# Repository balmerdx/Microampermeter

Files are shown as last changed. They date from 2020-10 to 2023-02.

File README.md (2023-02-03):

# Микроамперметр

Микроамперметр перфекциониста, с возможностью посмотреть график и гистограмму получаемого тока.
Предназначен для того, что-бы отлаживать низкопотребляющие железки,
которые во сне потребляют микроамперы, а когда проснулись, то могут потреблять десятки миллиампер.

* [Видео с возможностями прибора.](https://www.youtube.com/watch?v=IdX-KkagfNQ)

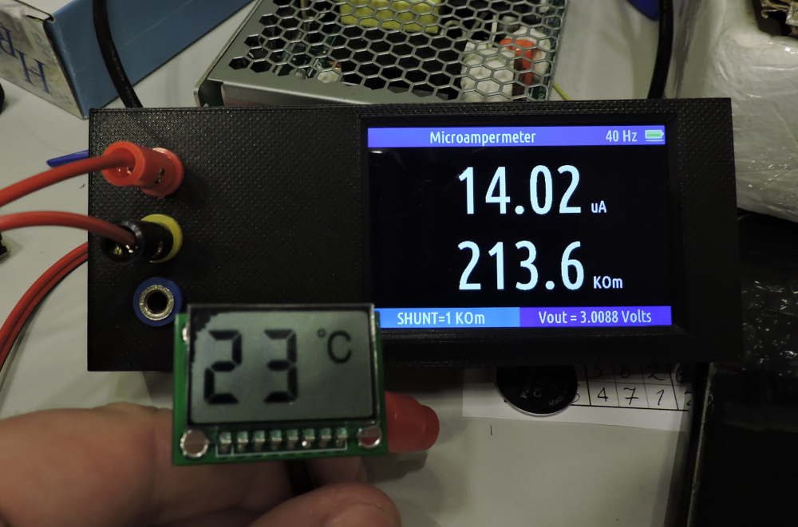
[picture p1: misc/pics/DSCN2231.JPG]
Плата


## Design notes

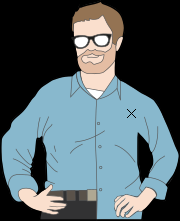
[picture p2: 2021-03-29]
misc/images/balmer.png

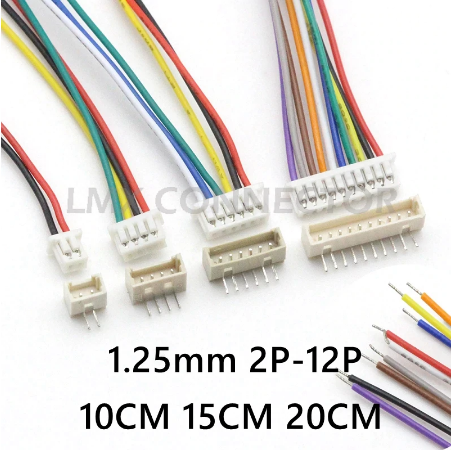
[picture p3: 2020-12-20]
kicad/stm32h7_digital/pinheader.png

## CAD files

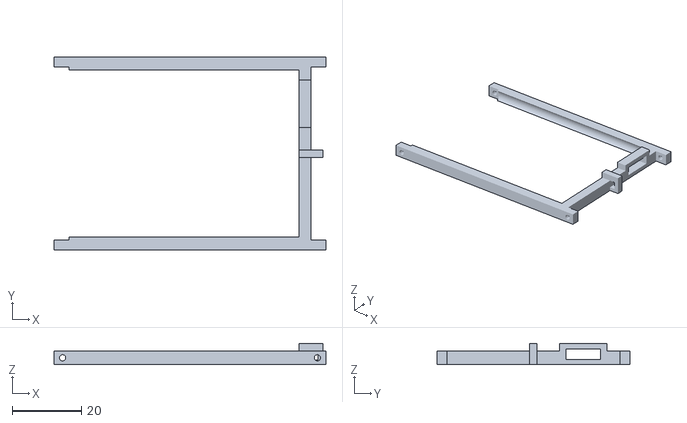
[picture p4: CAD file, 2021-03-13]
misc/3d/battery_holder.stl
78.7 x 55.8 x 6.20

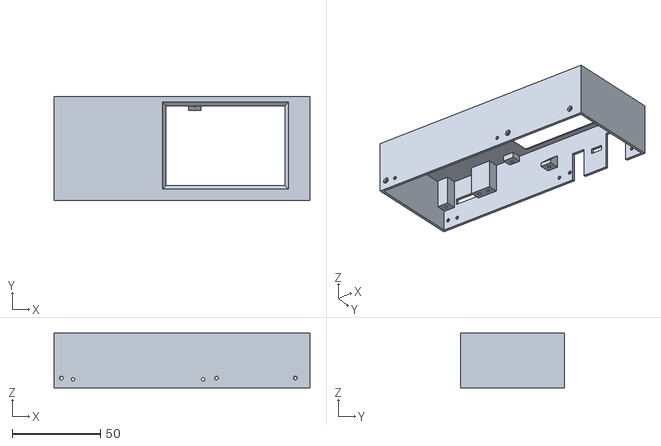
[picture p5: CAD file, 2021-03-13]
misc/3d/microampermeter_top.stl
145.0 x 58.8 x 31.0

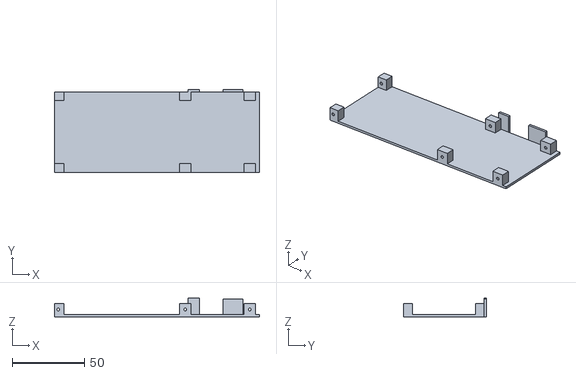
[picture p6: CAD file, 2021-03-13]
misc/3d/microampermeter_bottom.stl
141.8 x 57.2 x 12.9

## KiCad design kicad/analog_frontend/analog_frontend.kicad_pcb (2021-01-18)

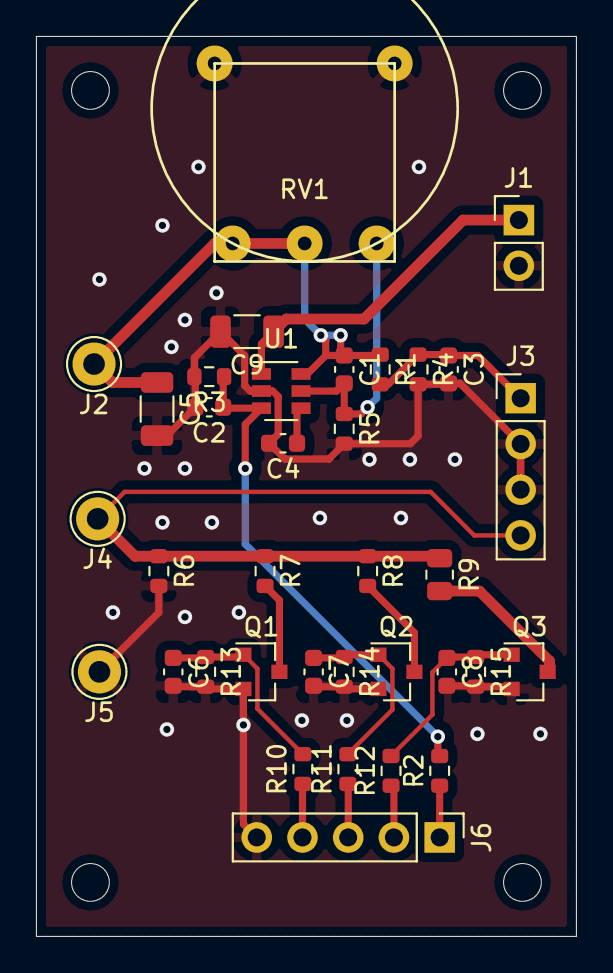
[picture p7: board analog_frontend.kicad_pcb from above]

Board: 2 copper layers, 30.0 x 50.0 mm, 35 parts (0 on the bottom side), 18 nets.

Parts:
C1: 22; C_0603_1608Metric
C2, C6, C7, C8: 22n; C_0603_1608Metric
C3: 1n; C_0603_1608Metric
C4: 10n; C_0603_1608Metric
C5: 25u; C_1206_3216Metric
C9: 10u; C_1206_3216Metric
J1: Power; PinHeader_1x02_P2.54mm_Vertical
J2: Vout; Pin_D1.0mm_L10.0mm_LooseFit
J3: ADC; PinHeader_1x04_P2.54mm_Vertical
J4: Isense; Pin_D1.0mm_L10.0mm_LooseFit
J5: GND; Pin_D1.0mm_L10.0mm_LooseFit
J6: Digital; PinHeader_1x05_P2.54mm_Vertical
Q1, Q2: SI2302; SOT-23
Q3: IRLML2502; SOT-23
R1, R4: 2k; R_0603_1608Metric
R2, R5: 10k; R_0603_1608Metric
R3: 330k; R_0603_1608Metric
R6: 1k; R_0603_1608Metric
R7: 100; R_0603_1608Metric
R8: 10; R_0603_1608Metric
R9: 1; R_0805_2012Metric
R10, R11, R12: 4.7k; R_0603_1608Metric
R13, R14, R15: 68k; R_0603_1608Metric
RV1: 20k; Potentiometer_10mm
U1: TPS79301-EP; SOT-23-6

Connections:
+BATT: C9.1, J1.1, U1.1
/Vout: C1.1, C5.1, J2.1, R1.1, RV1.1, RV1.2, U1.6
EN_V: J6.1, R2.1
GND: C2.2, C3.2, C4.2, C5.2, C6.2, C7.2, C8.2, C9.2, J1.2, J3.2, J3.3, J5.1, J6.5, Q1.2, Q2.2, Q3.2, R3.2, R4.2, R5.2, R6.2, R13.2, R14.2, R15.2, RV1.4, RV1.5, U1.2
I_ADC: J3.4, J4.1, R6.1, R7.1, R8.1, R9.1
unnamed: C1.2, R5.1, RV1.3, U1.5
unnamed: C2.1, R2.2, R3.1, U1.3
unnamed: C4.1, U1.4
unnamed: C6.1, Q1.1, R10.2, R13.1
unnamed: C7.1, Q2.1, R11.2, R14.1
unnamed: C8.1, Q3.1, R12.2, R15.1
unnamed: Q1.3, R7.2
unnamed: Q2.3, R8.2
unnamed: Q3.3, R9.2
ON_1: J6.2, R12.1
ON_10: J6.3, R11.1
ON_100: J6.4, R10.1
V_ADC: C3.1, J3.1, R1.2, R4.1

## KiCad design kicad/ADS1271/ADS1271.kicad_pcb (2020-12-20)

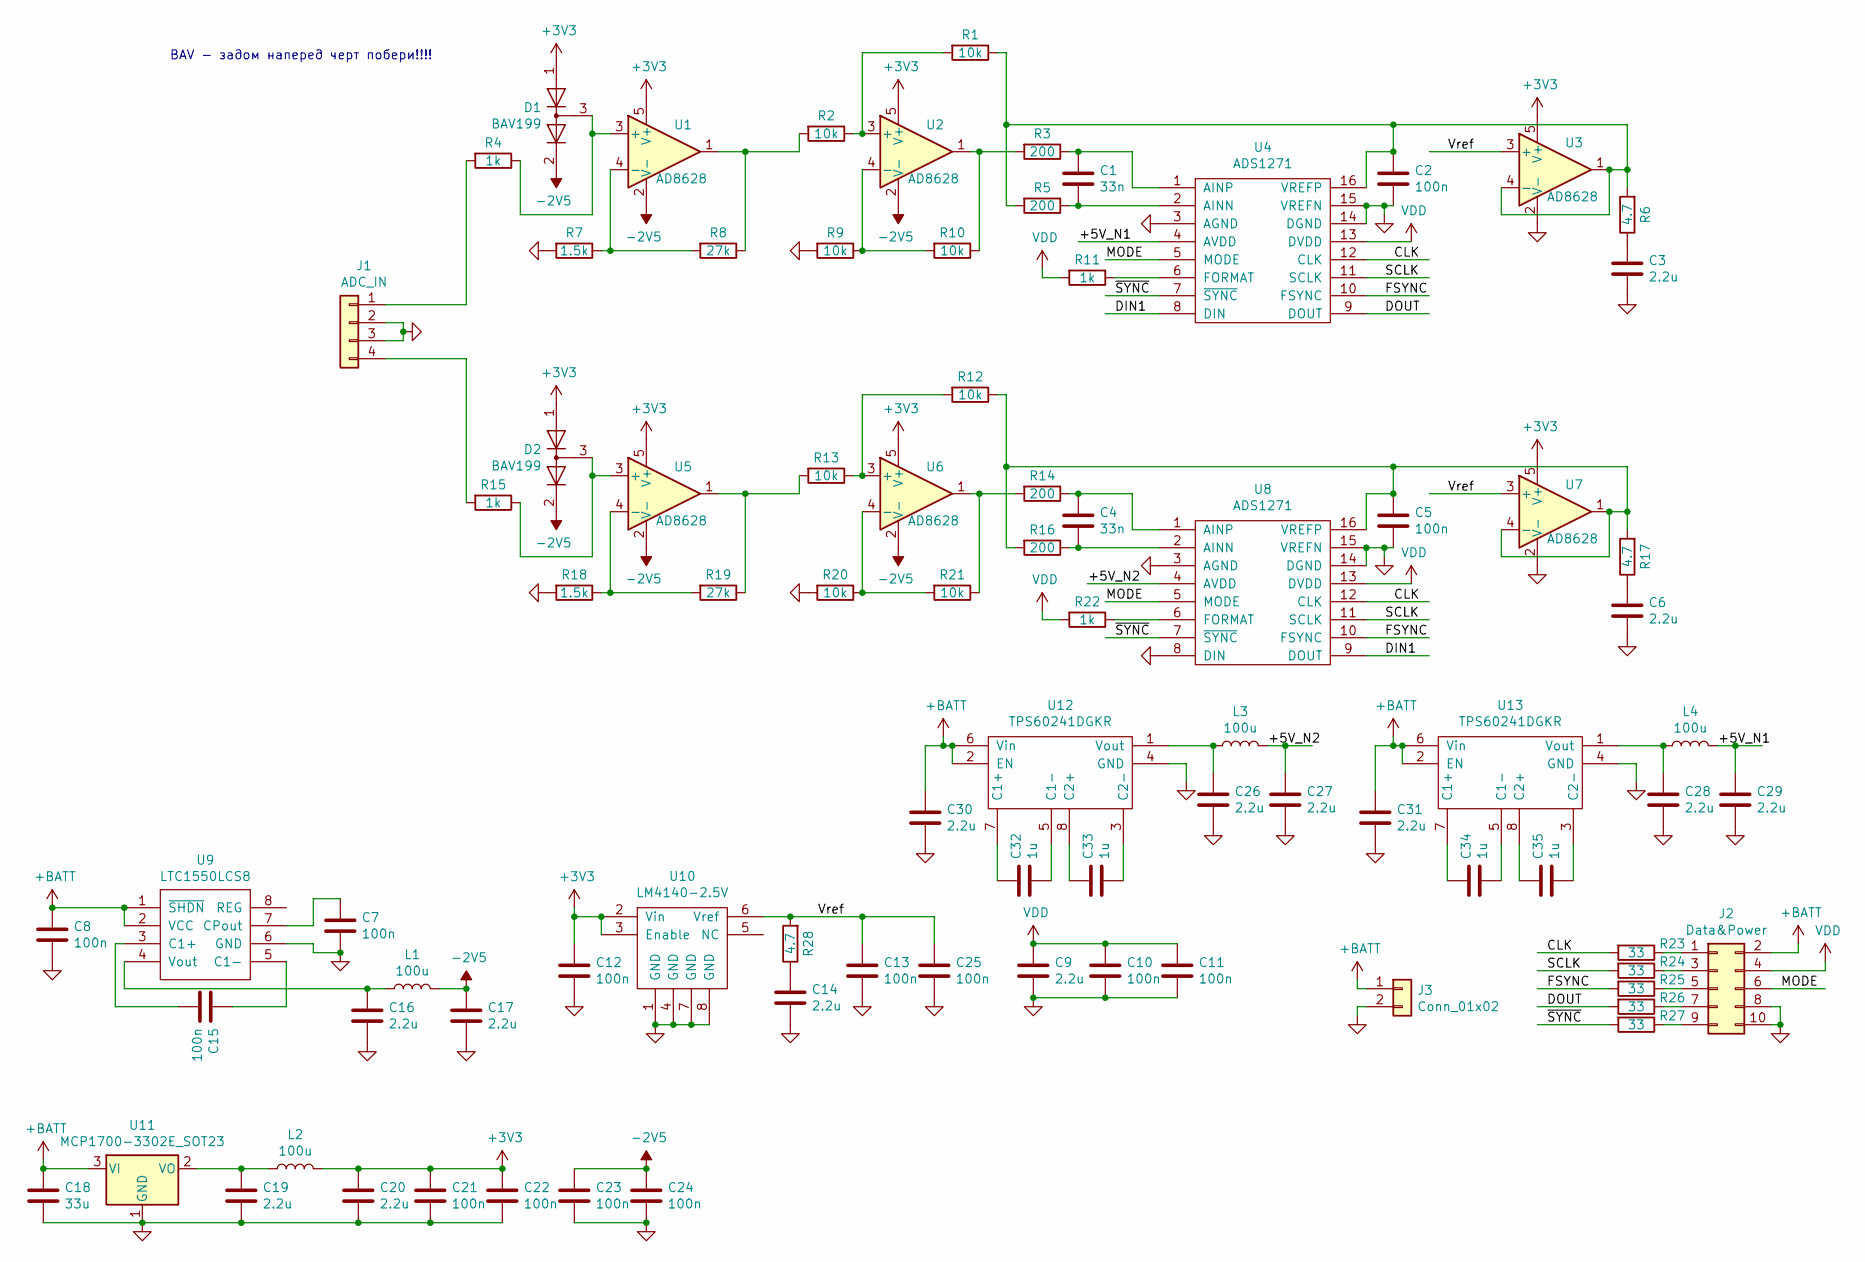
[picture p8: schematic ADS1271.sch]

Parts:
C1, C4: 33n; C_Disc_D7.5mm_W2.5mm_P5.00mm
C2, C5, C7, C8, C10, C11, C12, C13, C15, C21, C22, C23, C24, C25: 100n; C_0603_1608Metric
C3, C6, C9, C14, C16, C17, C19, C20, C26, C27, C28, C29, C30, C31: 2.2u; C_0805_2012Metric
C18: 33u; C_1206_3216Metric
C32, C33, C34, C35: 1u; C_0603_1608Metric
D1, D2: BAV199; SOT-23
J1: ADC_IN; PinHeader_1x04_P2.54mm_Vertical
J2: Data&Power; PinHeader_2x05_P2.54mm_Horizontal
J3: Conn_01x02; PinHeader_1x02_P2.54mm_Vertical
L1, L2, L3, L4: 100u; L_Axial_L9.5mm_D4.0mm_P12.70mm_Horizontal_Fastron_SMCC
R1, R2, R9, R10, R12, R13, R20, R21: 10k; R_0603_1608Metric
R3, R5, R14, R16: 200; R_0603_1608Metric
R4, R11, R15, R22: 1k; R_0603_1608Metric
R6, R17, R28: 4.7; R_0603_1608Metric
R7, R18: 1.5k; R_0603_1608Metric
R8, R19: 27k; R_0603_1608Metric
R23, R24, R25, R26, R27: 33; R_0603_1608Metric
U1, U2, U3, U5, U6, U7: AD8628; SOT-23-5
U4, U8: ADS1271; TSSOP-16_4.4x5mm_P0.65mm
U9: LTC1550LCS8; TSSOP-8_3x3mm_P0.65mm
U10: LM4140-2.5V; SO-8_3.9x4.9mm_P1.27mm
U11: MCP1700-3302E_SOT23; SOT-23
U12, U13: TPS60241DGKR; TSSOP-8_3x3mm_P0.65mm

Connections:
+3V3: C12.1, C20.1, C21.1, C22.1, D1.1 (K), D2.1 (K), L2.2, U1.5 (V+), U2.5 (V+), U3.5 (V+), U5.5 (V+), U6.5 (V+), U7.5 (V+), U10.2 (Vin), U10.3 (Enable)
+BATT: C8.1, C18.1, C30.1, C31.1, J2.2, J3.1, U9.1 (~SHDN), U9.2 (VCC), U11.3 (VI), U12.2 (EN), U12.6 (Vin), U13.2 (EN), U13.6 (Vin)
-2V5: C17.1, C23.1, C24.1, D1.2 (A), D2.2 (A), L1.2, U1.2 (V-), U2.2 (V-), U5.2 (V-), U6.2 (V-)
/+5V_N1: C29.1, L4.2, U4.4 (AVDD)
/+5V_N2: C27.1, L3.2, U8.4 (AVDD)
/CLK: R23.2, U4.12 (CLK), U8.12 (CLK)
/DIN1: U4.8 (DIN), U8.9 (DOUT)
/DOUT: R26.2, U4.9 (DOUT)
/FSYNC: R25.2, U4.10 (FSYNC), U8.10 (FSYNC)
/MODE: J2.6, U4.5 (MODE), U8.5 (MODE)
/SCLK: R24.2, U4.11 (SCLK), U8.11 (SCLK)
/Vref: C13.1, C25.1, R28.2, U3.3 (+), U7.3 (+), U10.6 (Vref)
/~SYNC: R27.2, U4.7 (~SYNC), U8.7 (~SYNC)
GND: C2.2, C3.2, C5.2, C6.2, C7.2, C8.2, C9.2, C10.2, C11.2, C12.2, C13.2, C14.2, C16.2, C17.2, C18.2, C19.2, C20.2, C21.2, C22.2, C23.2, C24.2, C25.2, C26.2, C27.2, C28.2, C29.2, C30.2, C31.2, J1.2, J1.3, J2.8, J2.10, J3.2, R7.2, R9.2, R18.2, R20.2, U3.2 (V-), U4.3 (AGND), U4.14 (DGND), U4.15 (VREFN), U7.2 (V-), U8.3 (AGND), U8.8 (DIN), U8.14 (DGND), U8.15 (VREFN), U9.6 (GND), U10.1 (GND), U10.4 (GND), U10.7 (GND), U10.8 (GND), U11.1 (GND), U12.4 (GND), U13.4 (GND)
unnamed: C1.1, R3.1, U4.1 (AINP)
unnamed: C1.2, R5.1, U4.2 (AINN)
unnamed: C2.1, R1.1, R5.2, R6.2, U3.1, U3.4 (-), U4.16 (VREFP)
unnamed: C3.1, R6.1
unnamed: C4.1, R14.1, U8.1 (AINP)
unnamed: C4.2, R16.1, U8.2 (AINN)
unnamed: C5.1, R12.1, R16.2, R17.2, U7.1, U7.4 (-), U8.16 (VREFP)
unnamed: C6.1, R17.1
unnamed: C7.1, U9.7 (CPout)
unnamed: C14.1, R28.1
unnamed: C15.1, U9.5 (C1-)
unnamed: C15.2, U9.3 (C1+)
unnamed: C16.1, L1.1, U9.4 (Vout)
unnamed: C19.1, L2.1, U11.2 (VO)
unnamed: C26.1, L3.1, U12.1 (Vout)
unnamed: C28.1, L4.1, U13.1 (Vout)
unnamed: C32.1, U12.7 (C1+)
unnamed: C32.2, U12.5 (C1-)
unnamed: C33.1, U12.8 (C2+)
unnamed: C33.2, U12.3 (C2-)
unnamed: C34.1, U13.7 (C1+)
unnamed: C34.2, U13.5 (C1-)
unnamed: C35.1, U13.8 (C2+)
unnamed: C35.2, U13.3 (C2-)
unnamed: D1.3 (K), R4.1, U1.3 (+)
unnamed: D2.3 (K), R15.1, U5.3 (+)
unnamed: J1.1, R4.2
unnamed: J1.4, R15.2
unnamed: J2.1, R23.1
unnamed: J2.3, R24.1
unnamed: J2.5, R25.1
unnamed: J2.7, R26.1
unnamed: J2.9, R27.1
unnamed: R1.2, R2.1, U2.3 (+)
unnamed: R2.2, R8.1, U1.1
unnamed: R7.1, R8.2, U1.4 (-)
unnamed: R3.2, R10.1, U2.1
unnamed: R9.1, R10.2, U2.4 (-)
unnamed: R11.1, U4.6 (FORMAT)
unnamed: R12.2, R13.1, U6.3 (+)
unnamed: R13.2, R19.1, U5.1
unnamed: R14.2, R21.1, U6.1
unnamed: R18.1, R19.2, U5.4 (-)
unnamed: R20.1, R21.2, U6.4 (-)
unnamed: R22.1, U8.6 (FORMAT)
VDD: C9.1, C10.1, C11.1, J2.4, R11.2, R22.2, U4.13 (DVDD), U8.13 (DVDD)

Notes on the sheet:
BAV - задом наперед черт побери!!!!

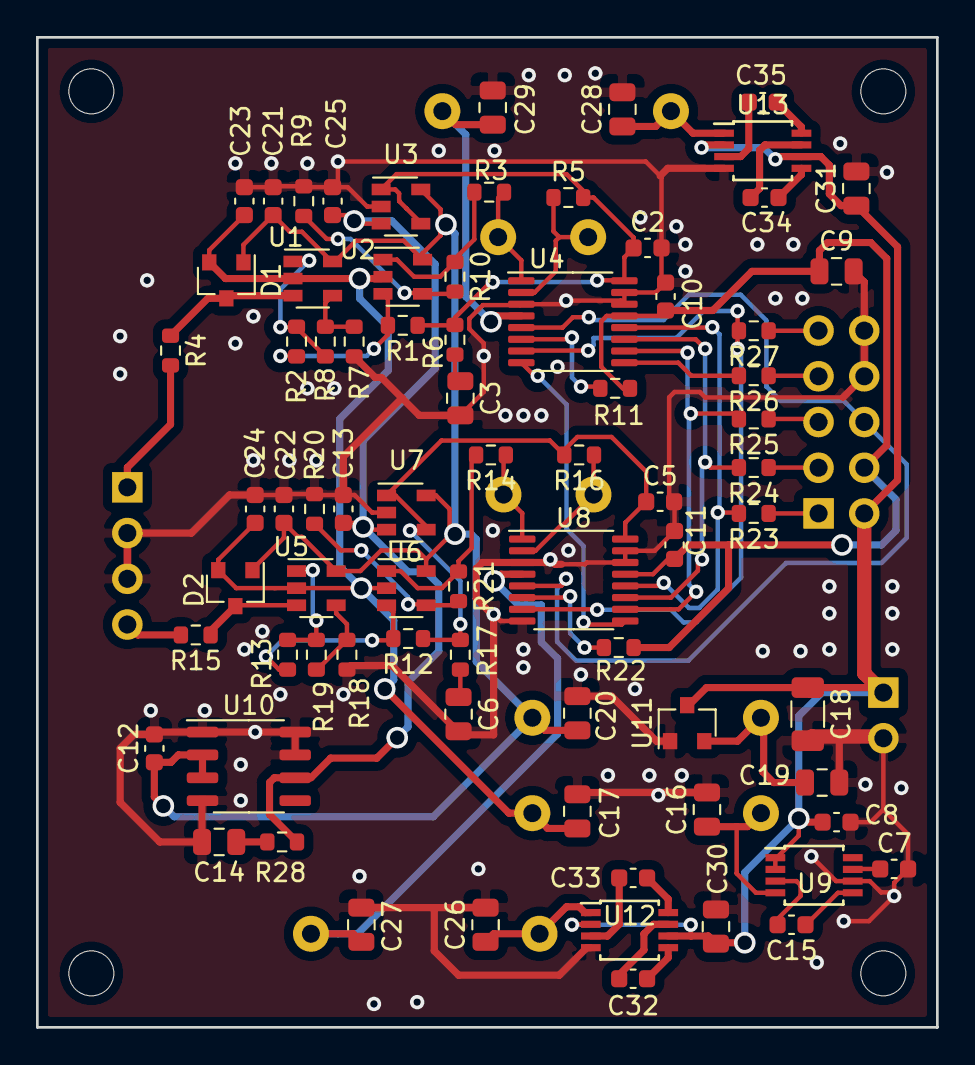
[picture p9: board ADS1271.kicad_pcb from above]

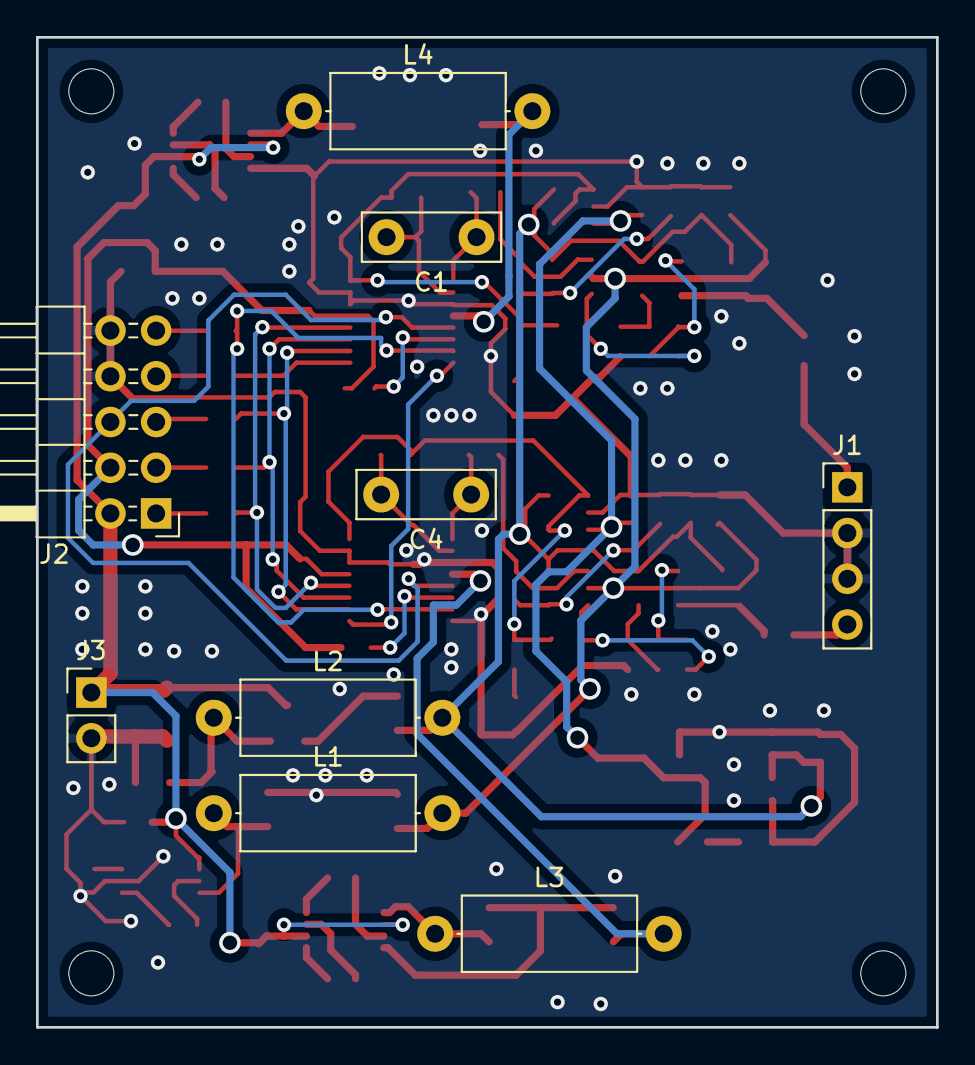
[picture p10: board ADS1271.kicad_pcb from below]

Board: 2 copper layers, 50.0 x 55.0 mm, 85 parts (9 on the bottom side), 60 nets.

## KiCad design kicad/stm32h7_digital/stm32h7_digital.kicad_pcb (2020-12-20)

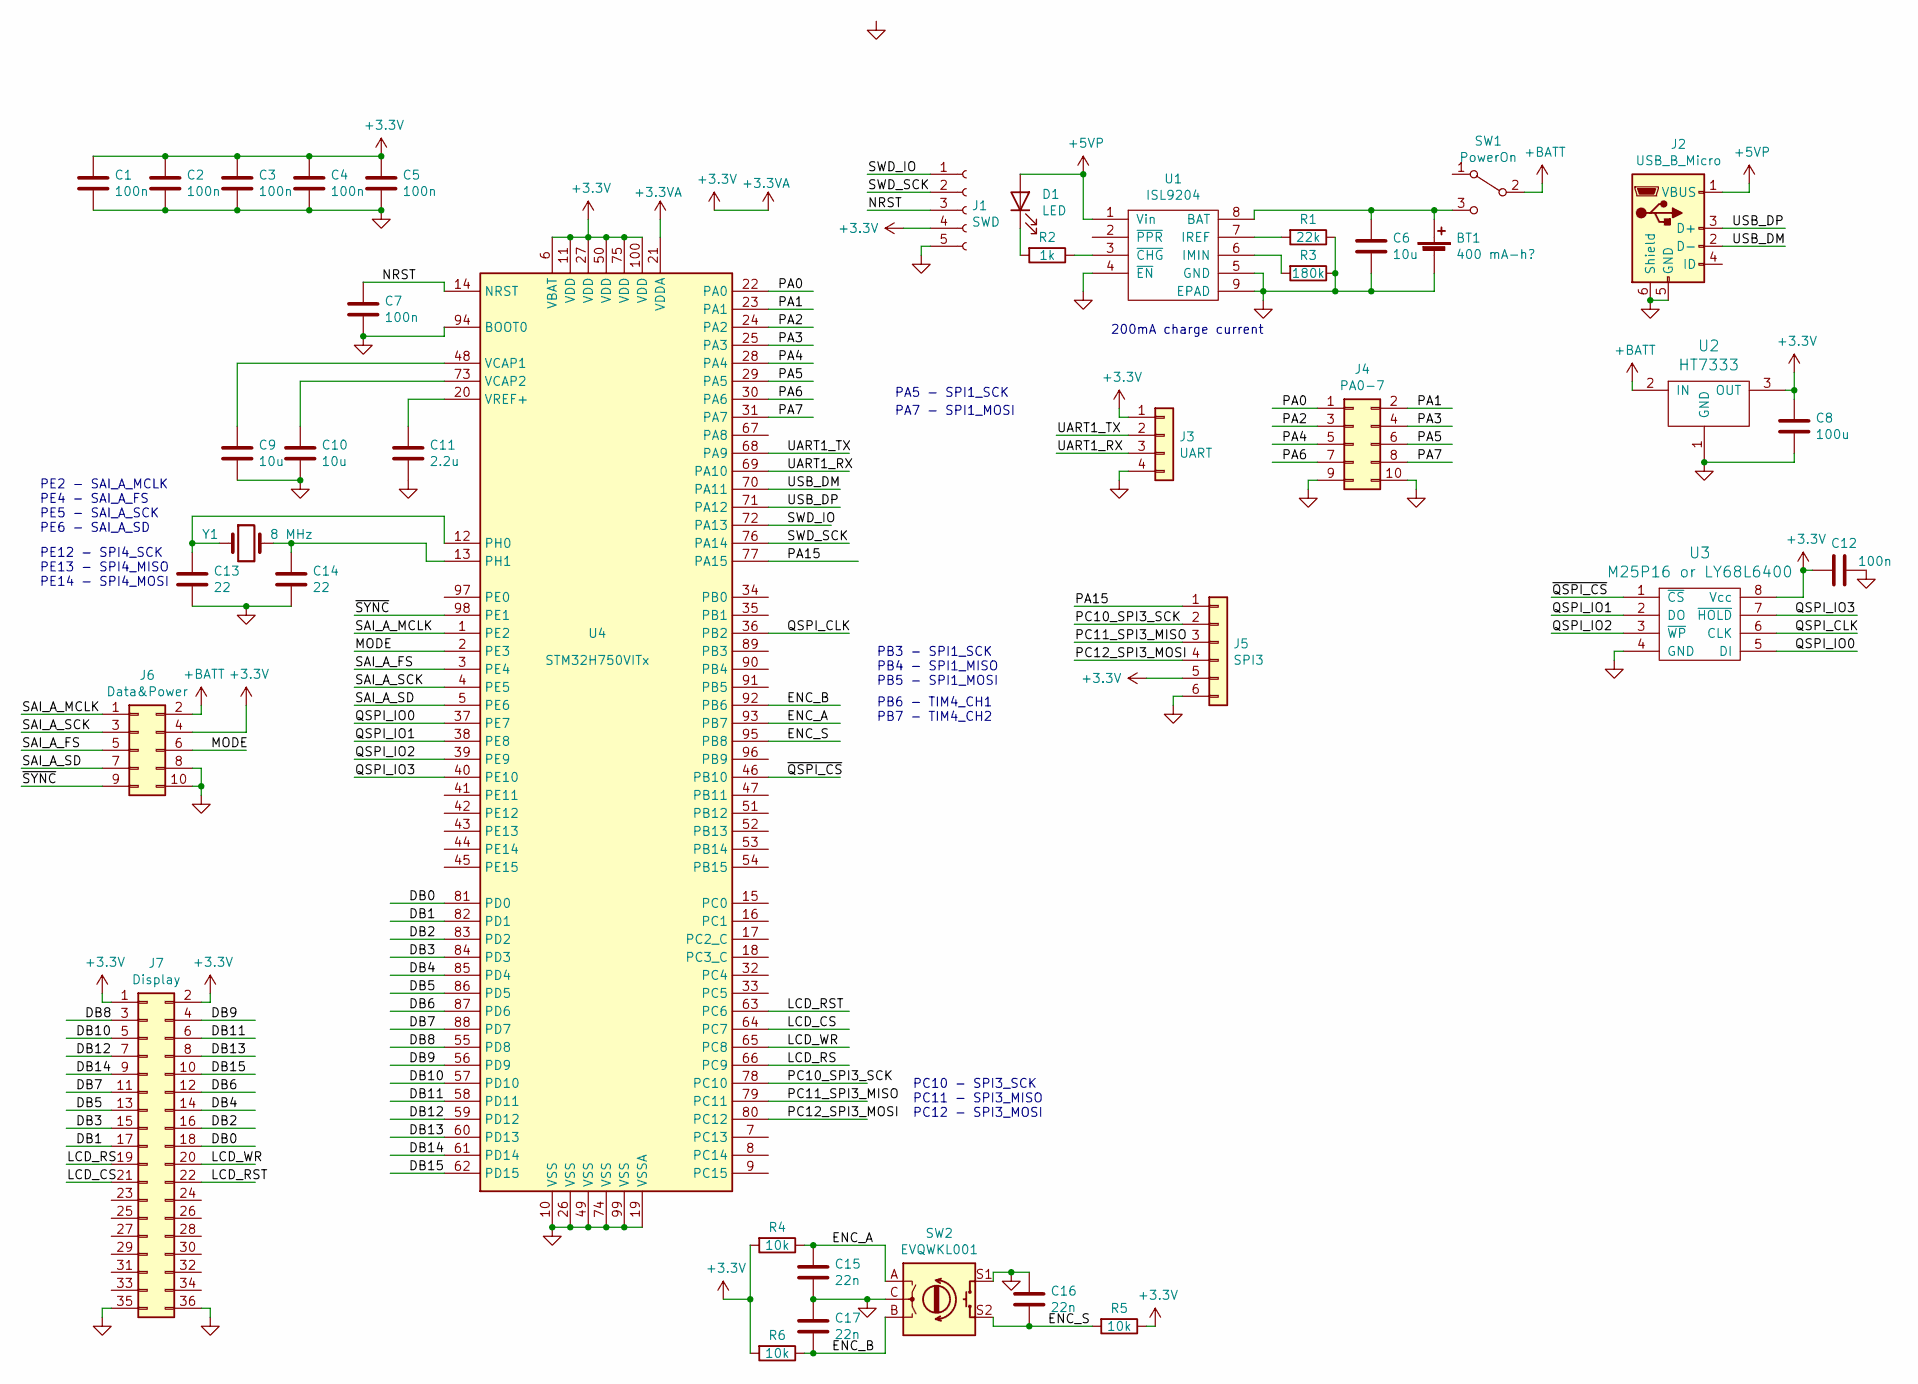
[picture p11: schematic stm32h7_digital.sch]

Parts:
BT1: 400 mA-h?; PinSocket_1x02_P2.54mm_Vertical
C1, C2, C3, C4, C5, C7, C12: 100n; C_0603_1608Metric
C6, C9, C10: 10u; C_1206_3216Metric
C8: 100u; C_1206_3216Metric
C11: 2.2u; C_0805_2012Metric
C13, C14: 22; C_0603_1608Metric
C15, C16, C17: 22n; C_0603_1608Metric
D1: LED; LED_0805_2012Metric_Pad1.15x1.40mm_HandSolder
J1: SWD; PinSocket_1x05_P1.27mm_Vertical
J2: USB_B_Micro; USB_Micro-B_Molex-105017-0001
J3: UART; PinHeader_1x04_P2.54mm_Horizontal
J4: PA0-7; PinSocket_2x05_P2.54mm_Horizontal
J5: SPI3; PinSocket_1x06_P1.27mm_Vertical
J6: Data&Power; PinSocket_2x05_P2.54mm_Horizontal
J7: Display; PinHeader_2x18_P2.54mm_Vertical
R1: 22k; R_0603_1608Metric
R2: 1k; R_0603_1608Metric
R3: 180k; R_0603_1608Metric
R4, R5, R6: 10k; R_0603_1608Metric
SW1: PowerOn; SW_Angled_with_GND
SW2: EVQWKL001; Encoder_EVQWK4
U1: ISL9204; DFN-8-1EP_3x2mm_P0.5mm_EP1.75x1.65mm
U2: HT7333; SOT-89-3
U3: M25P16 or LY68L6400; SOIC-8_3.9x4.9mm_P1.27mm
U4: STM32H750VITx; LQFP-100_14x14mm_P0.5mm
Y1: 8 MHz; Crystal_SMD_5032-2Pin_5.0x3.2mm

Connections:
+3.3VA: C1.1, C2.1, C3.1, C4.1, C5.1, C8.1, C12.2, J1.4, J3.1, J5.5, J6.4, J7.1, J7.2, R4.2, R5.1, R6.2, U2.3 (OUT), U3.8 (Vcc), U4.6 (VBAT), U4.11 (VDD), U4.21 (VDDA), U4.27 (VDD), U4.50 (VDD), U4.75 (VDD), U4.100 (VDD)
+5VP: D1.2 (A), J2.1 (VBUS), U1.1 (Vin)
+BATT: J6.2, SW1.2 (B), U2.2 (IN)
/DB0: J7.18, U4.81 (PD0)
/DB1: J7.17, U4.82 (PD1)
/DB2: J7.16, U4.83 (PD2)
/DB3: J7.15, U4.84 (PD3)
/DB4: J7.14, U4.85 (PD4)
/DB5: J7.13, U4.86 (PD5)
/DB6: J7.12, U4.87 (PD6)
/DB7: J7.11, U4.88 (PD7)
/DB8: J7.3, U4.55 (PD8)
/DB9: J7.4, U4.56 (PD9)
/DB10: J7.5, U4.57 (PD10)
/DB11: J7.6, U4.58 (PD11)
/DB12: J7.7, U4.59 (PD12)
/DB13: J7.8, U4.60 (PD13)
/DB14: J7.9, U4.61 (PD14)
/DB15: J7.10, U4.62 (PD15)
/ENC_A: C15.1, R4.1, SW2.A, U4.93 (PB7)
/ENC_B: C17.2, R6.1, SW2.B, U4.92 (PB6)
/ENC_S: C16.2, R5.2, SW2.S2, U4.95 (PB8)
/LCD_CS: J7.21, U4.64 (PC7)
/LCD_RS: J7.19, U4.66 (PC9)
/LCD_RST: J7.22, U4.63 (PC6)
/LCD_WR: J7.20, U4.65 (PC8)
/MODE: J6.6, U4.2 (PE3)
/NRST: C7.1, J1.3, U4.14 (NRST)
/PA0: J4.1, U4.22 (PA0)
/PA1: J4.2, U4.23 (PA1)
/PA2: J4.3, U4.24 (PA2)
/PA3: J4.4, U4.25 (PA3)
/PA4: J4.5, U4.28 (PA4)
/PA5: J4.6, U4.29 (PA5)
/PA6: J4.7, U4.30 (PA6)
/PA7: J4.8, U4.31 (PA7)
/PA15: J5.1, U4.77 (PA15)
/PC10_SPI3_SCK: J5.2, U4.78 (PC10)
/PC11_SPI3_MISO: J5.3, U4.79 (PC11)
/PC12_SPI3_MOSI: J5.4, U4.80 (PC12)
/QSPI_CLK: U3.6 (CLK), U4.36 (PB2)
/QSPI_IO0: U3.5 (DI), U4.37 (PE7)
/QSPI_IO1: U3.2 (DO), U4.38 (PE8)
/QSPI_IO2: U3.3 (~WP), U4.39 (PE9)
/QSPI_IO3: U3.7 (~HOLD), U4.40 (PE10)
/SAI_A_FS: J6.5, U4.3 (PE4)
/SAI_A_MCLK: J6.1, U4.1 (PE2)
/SAI_A_SCK: J6.3, U4.4 (PE5)
/SAI_A_SD: J6.7, U4.5 (PE6)
/SWD_IO: J1.1, U4.72 (PA13)
/SWD_SCK: J1.2, U4.76 (PA14)
/UART1_RX: J3.3, U4.69 (PA10)
/UART1_TX: J3.2, U4.68 (PA9)
/USB_DM: J2.2 (D-), U4.70 (PA11)
/USB_DP: J2.3 (D+), U4.71 (PA12)
/~QSPI_CS: U3.1 (~CS), U4.46 (PB10)
/~SYNC: J6.9, U4.98 (PE1)
GND: BT1.2 (-), C1.2, C2.2, C3.2, C4.2, C5.2, C6.2, C7.2, C8.2, C9.2, C10.2, C11.2, C12.1, C13.2, C14.2, C15.2, C16.1, C17.1, J1.5, J2.5 (GND), J2.6 (Shield), J3.4, J4.9, J4.10, J5.6, J6.8, J6.10, J7.35, J7.36, R1.1, R3.1, SW2.C, SW2.GND, SW2.PAD, SW2.S1, U1.4 (~EN), U1.5 (GND), U1.9 (EPAD), U2.1 (GND), U3.4 (GND), U4.10 (VSS), U4.19 (VSSA), U4.26 (VSS), U4.49 (VSS), U4.74 (VSS), U4.94 (BOOT0), U4.99 (VSS)
unnamed: BT1.1 (+), C6.1, SW1.3 (C), U1.8 (BAT)
unnamed: C9.1, U4.48 (VCAP1)
unnamed: C10.1, U4.73 (VCAP2)
unnamed: C11.1, U4.20 (VREF+)
unnamed: C13.1, U4.12 (PH0), Y1.1
unnamed: C14.1, U4.13 (PH1), Y1.2
unnamed: D1.1 (K), R2.2
unnamed: R1.2, U1.7 (IREF)
unnamed: R2.1, U1.3 (~CHG)
unnamed: R3.2, U1.6 (IMIN)

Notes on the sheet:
200mA charge current
PB3 - SPI1_SCK PB4 - SPI1_MISO PB5 - SPI1_MOSI
PC10 - SPI3_SCK PC11 - SPI3_MISO PC12 - SPI3_MOSI
PB6 - TIM4_CH1 PB7 - TIM4_CH2
PA5 - SPI1_SCK
PA7 - SPI1_MOSI
PE12 - SPI4_SCK PE13 - SPI4_MISO PE14 - SPI4_MOSI
PE2 - SAI_A_MCLK PE4 - SAI_A_FS PE5 - SAI_A_SCK PE6 - SAI_A_SD

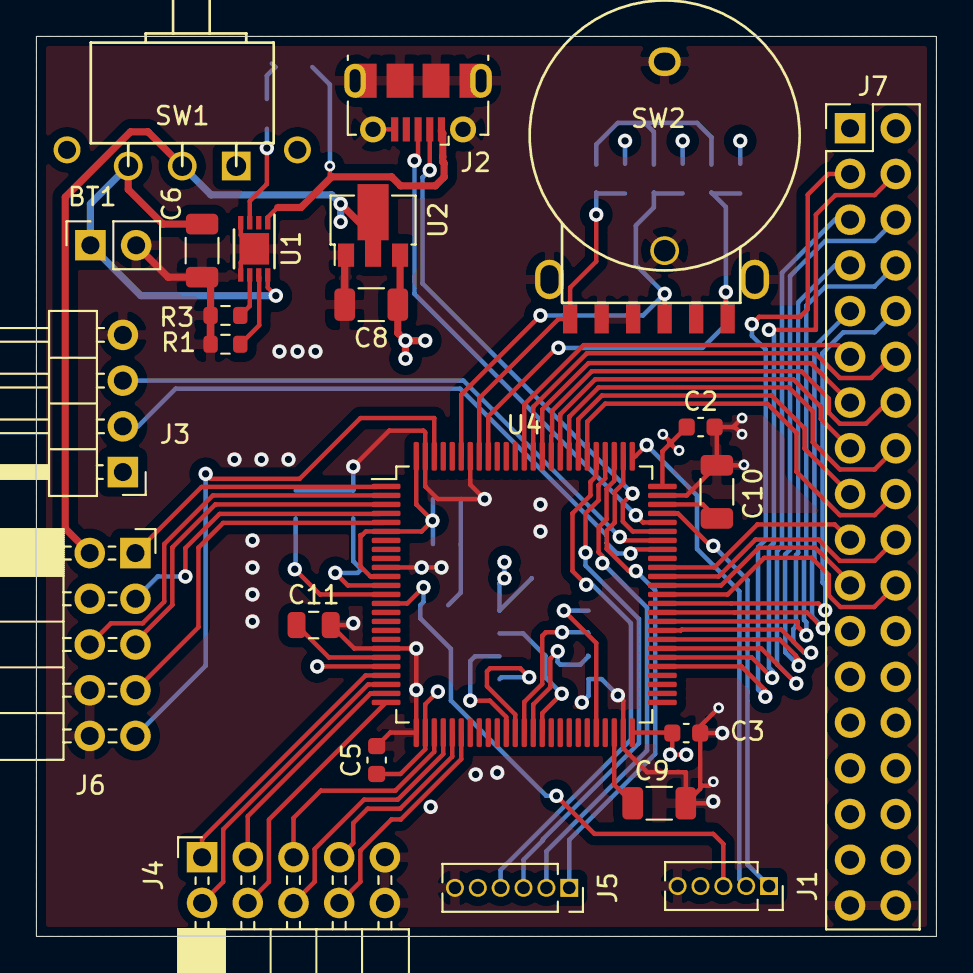
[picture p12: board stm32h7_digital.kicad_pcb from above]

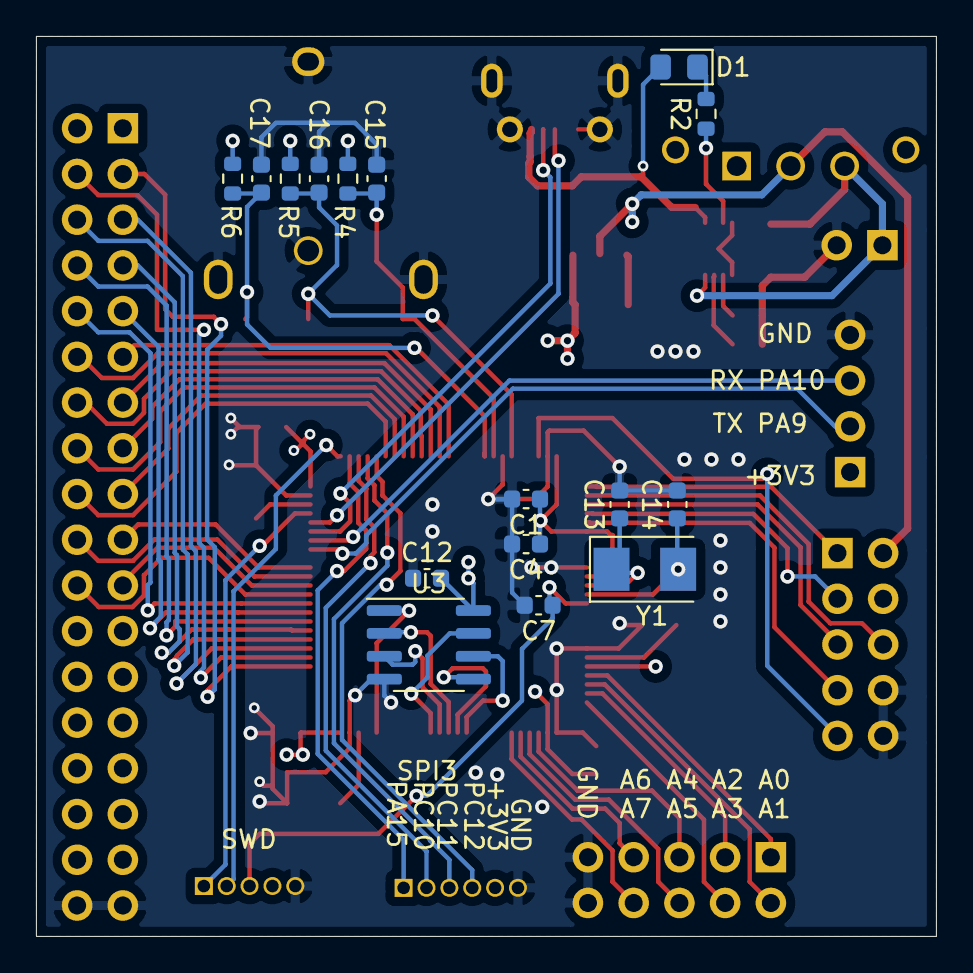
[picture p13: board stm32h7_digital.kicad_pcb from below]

Board: 4 copper layers, 50.0 x 50.0 mm, 39 parts (16 on the bottom side), 68 nets.

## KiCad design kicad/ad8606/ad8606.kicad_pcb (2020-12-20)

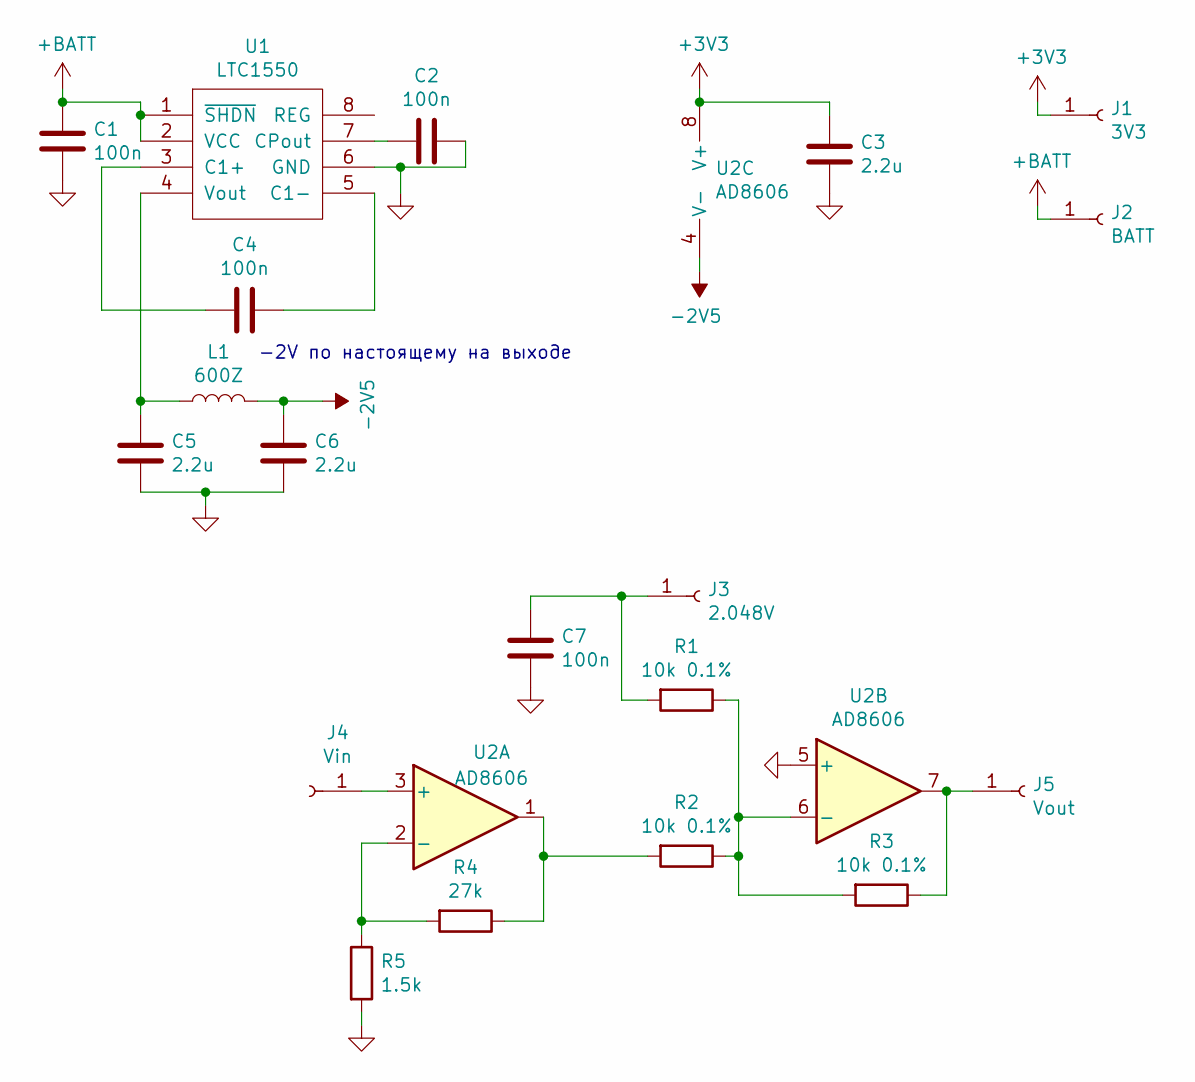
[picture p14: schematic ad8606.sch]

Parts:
C1, C2, C4, C7: 100n; C_0603_1608Metric
C3, C5, C6: 2.2u; C_0805_2012Metric
J1: 3V3; TestPoint_Pad_1.5x1.5mm
J2: BATT; TestPoint_Pad_1.5x1.5mm
J3: 2.048V; TestPoint_Pad_1.5x1.5mm
J4: Vin; TestPoint_Pad_1.5x1.5mm
J5: Vout; TestPoint_Pad_1.5x1.5mm
L1: 600Z; L_1206_3216Metric
R1, R2, R3: 10k 0.1%; R_0603_1608Metric
R4: 27k; R_0603_1608Metric
R5: 1.5k; R_0603_1608Metric
U1: LTC1550; TSSOP-8_3x3mm_P0.65mm
U2: AD8606; TSSOP-8_3x3mm_P0.65mm

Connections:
+3V3: C3.1, J1.1, U2.8 (V+)
+BATT: C1.2, J2.1, U1.1 (~SHDN), U1.2 (VCC)
-2V5: C6.1, L1.2, U2.4 (V-)
GND: C1.1, C2.1, C3.2, C5.2, C6.2, C7.1, R5.2, U1.6 (GND), U2.5 (+)
unnamed: C2.2, U1.7 (CPout)
unnamed: C4.1, U1.5 (C1-)
unnamed: C4.2, U1.3 (C1+)
unnamed: C5.1, L1.1, U1.4 (Vout)
unnamed: C7.2, J3.1, R1.2
unnamed: J4.1, U2.3 (+)
unnamed: J5.1, R3.1, U2.7
unnamed: R1.1, R2.1, R3.2, U2.6 (-)
unnamed: R2.2, R4.1, U2.1
unnamed: R4.2, R5.1, U2.2 (-)

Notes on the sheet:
-2V по настоящему на выходе

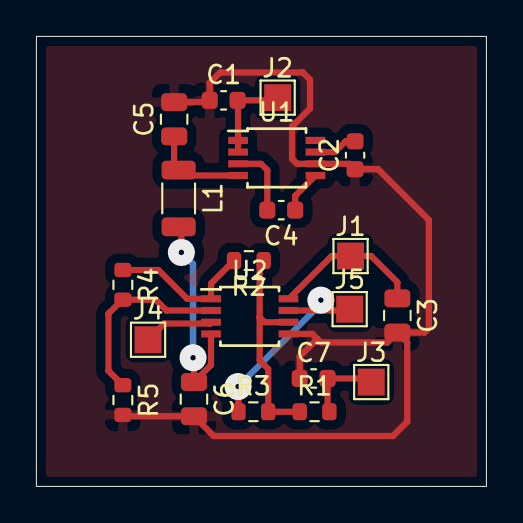
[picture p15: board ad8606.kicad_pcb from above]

Board: 2 copper layers, 25.0 x 25.0 mm, 20 parts (0 on the bottom side), 14 nets.

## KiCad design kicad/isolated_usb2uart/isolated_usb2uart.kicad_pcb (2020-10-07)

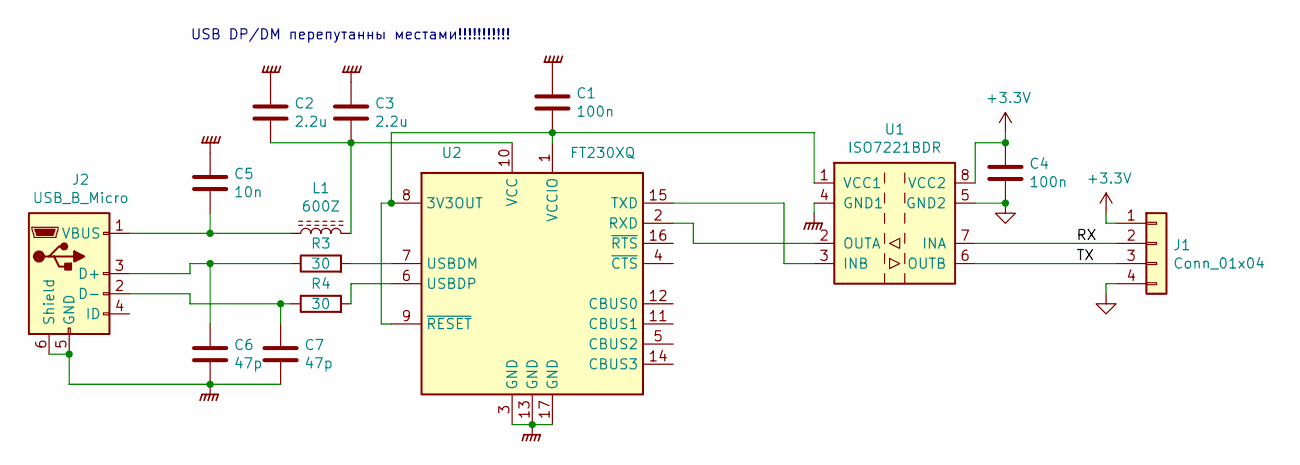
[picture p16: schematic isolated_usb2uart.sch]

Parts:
C1, C4: 100n; C_0603_1608Metric
C2, C3: 2.2u; C_0805_2012Metric
C5: 10n; C_0603_1608Metric
C6, C7: 47p; C_0603_1608Metric
J1: Conn_01x04; PinHeader_1x04_P2.54mm_Horizontal
J2: USB_B_Micro; USB_Micro-B_Molex-105017-0001
L1: 600Z; R_1206_3216Metric
R3, R4: 30; R_0603_1608Metric
U1: ISO7221BDR; SOIC-8_3.9x4.9mm_P1.27mm
U2: FT230XQ; QFN-16-1EP_4x4mm_P0.65mm_EP2.1x2.1mm

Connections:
+3V3: C4.1, J1.1, U1.8 (VCC2)
/RX: J1.2, U1.7 (INA)
/TX: J1.3, U1.6 (OUTB)
GND: C4.2, J1.4, U1.5 (GND2)
GNDPWR: C1.1, C2.1, C3.1, C5.1, C6.2, C7.2, J2.5 (GND), J2.6 (Shield), U1.4 (GND1), U2.3 (GND), U2.13 (GND), U2.17 (GND)
unnamed: C1.2, U1.1 (VCC1), U2.1 (VCCIO), U2.8 (3V3OUT), U2.9 (~RESET)
unnamed: C2.2, C3.2, L1.2, U2.10 (VCC)
unnamed: C5.2, J2.1 (VBUS), L1.1
unnamed: C6.1, J2.3 (D+), R3.1
unnamed: C7.1, J2.2 (D-), R4.1
unnamed: R3.2, U2.7 (USBDM)
unnamed: R4.2, U2.6 (USBDP)
unnamed: U1.2 (OUTA), U2.2 (RXD)
unnamed: U1.3 (INB), U2.15 (TXD)

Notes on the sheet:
USB DP/DM перепутанны местами!!!!!!!!!!!

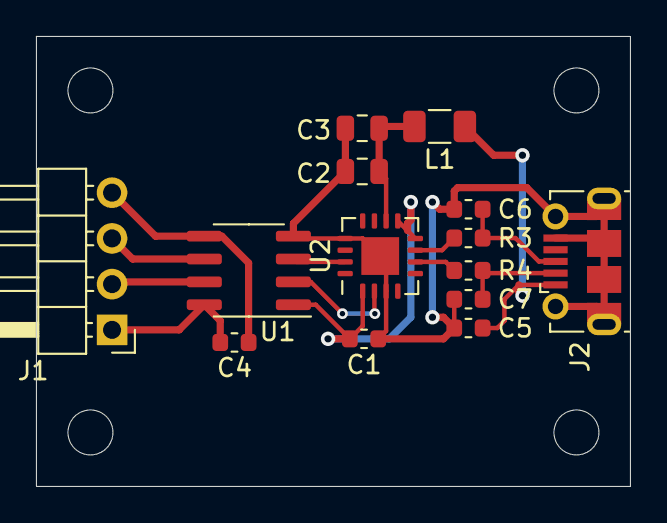
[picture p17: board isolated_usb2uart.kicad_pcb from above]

Board: 2 copper layers, 33.0 x 25.0 mm, 14 parts (0 on the bottom side), 14 nets.

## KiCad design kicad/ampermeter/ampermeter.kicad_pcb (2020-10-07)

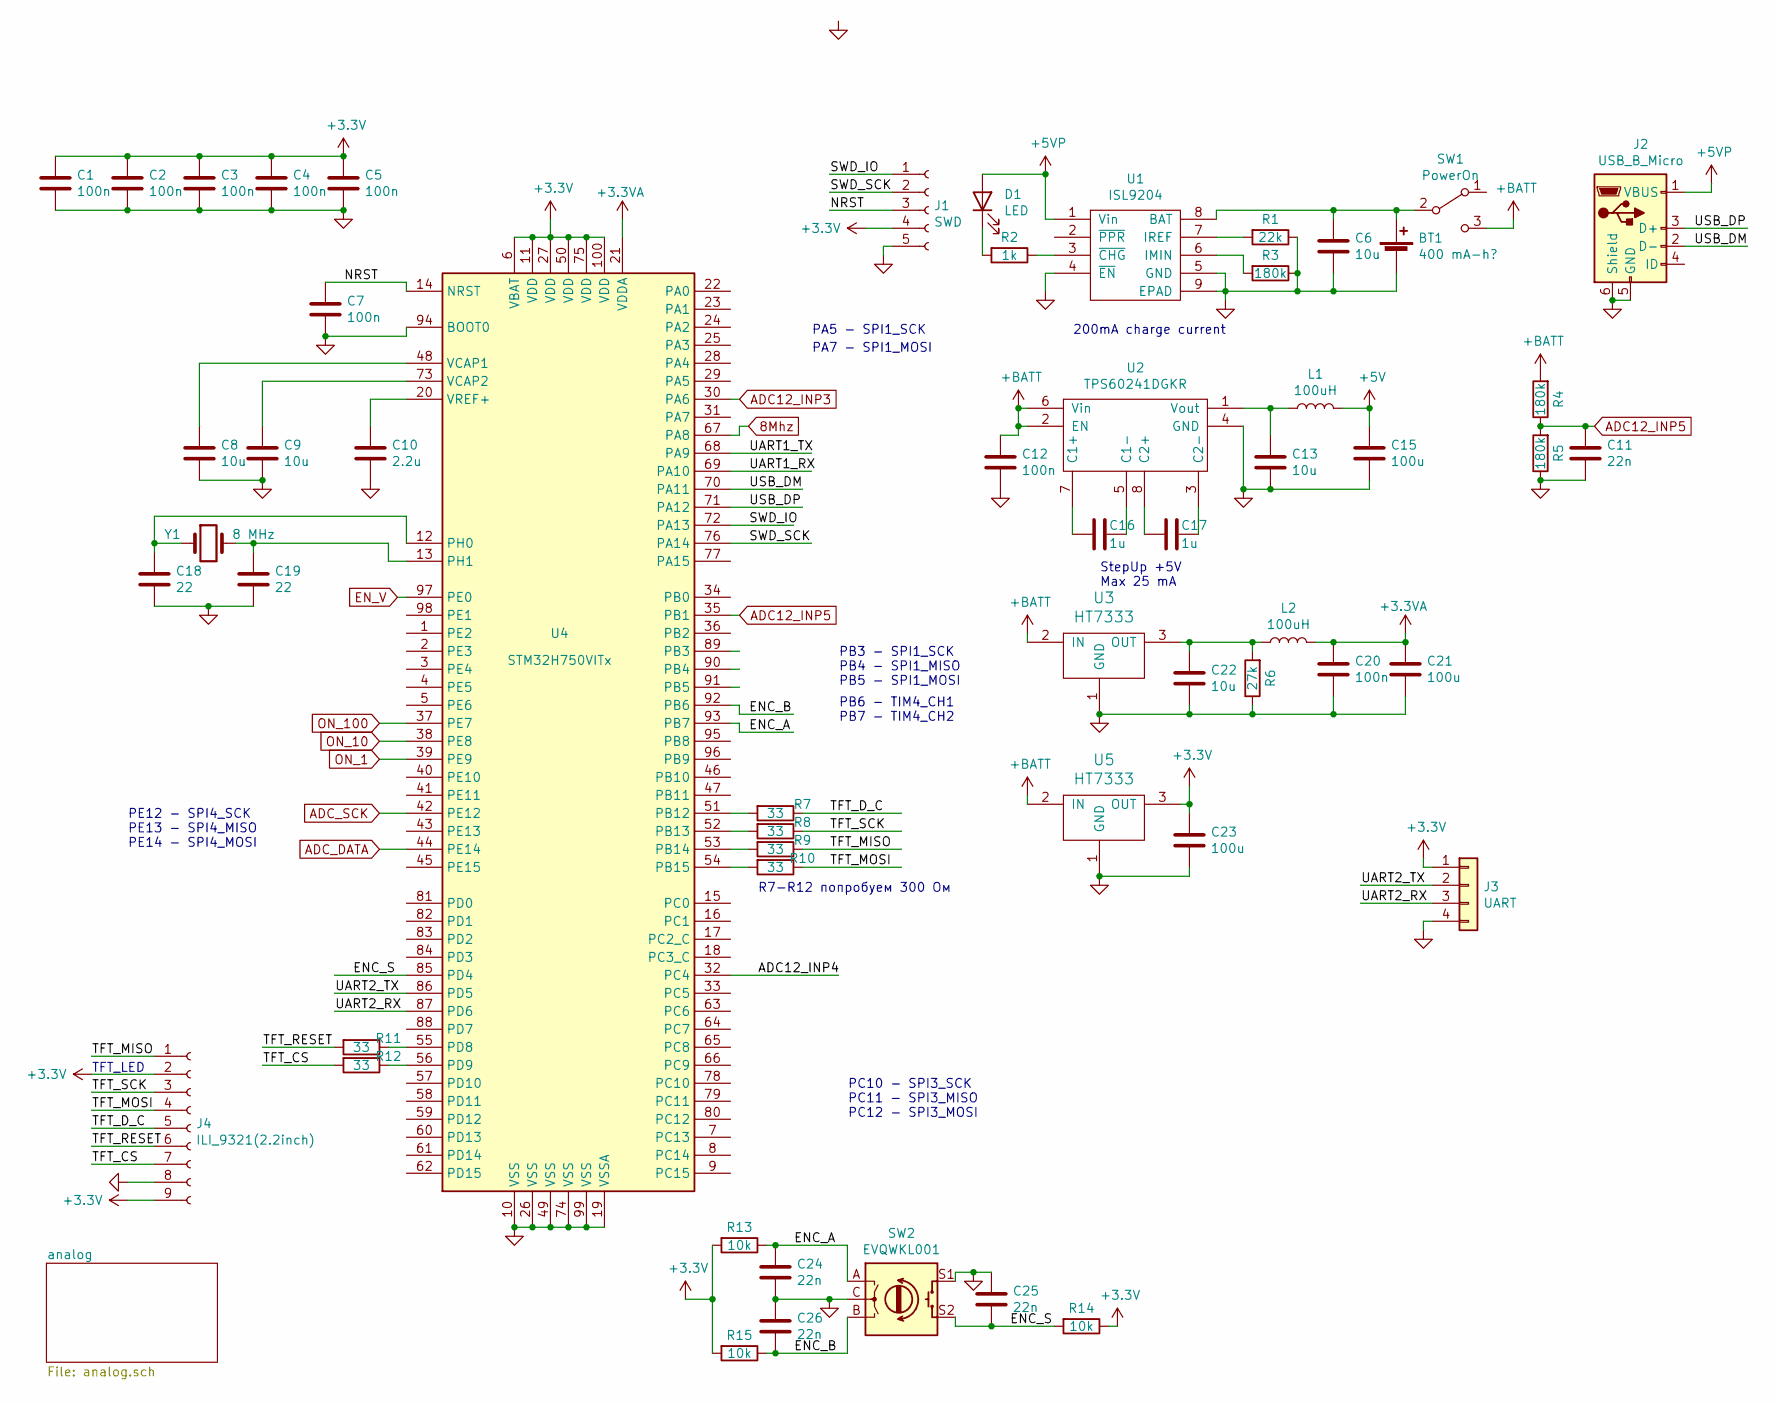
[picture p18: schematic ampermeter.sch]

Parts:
BT1: 400 mA-h?; PinSocket_1x02_P2.54mm_Vertical
C1, C2, C3, C4, C5, C7, C12, C20: 100n; C_0603_1608Metric
C6, C8, C9, C13, C22: 10u; C_1206_3216Metric
C10: 2.2u; C_0805_2012Metric
C11, C24, C25, C26: 22n; C_0603_1608Metric
C15, C21, C23: 100u; C_1206_3216Metric
C16, C17: 1u; C_0805_2012Metric
C18, C19: 22; C_0603_1608Metric
D1: LED; LED_0805_2012Metric_Pad1.15x1.40mm_HandSolder
J1: SWD; PinSocket_1x05_P1.27mm_Vertical
J2: USB_B_Micro; USB_Micro-B_Molex-105017-0001
J3: UART; PinHeader_1x04_P2.54mm_Horizontal
J4: ILI_9321(2.2inch)
L1, L2: 100uH; L_Axial_L5.3mm_D2.2mm_P7.62mm_Horizontal_Vishay_IM-1
R1: 22k; R_0603_1608Metric
R2: 1k; R_0603_1608Metric
R3, R4, R5: 180k; R_0603_1608Metric
R6: 27k; R_0603_1608Metric
R7, R8, R9, R10, R11, R12: 33; R_0603_1608Metric
R13, R14, R15: 10k; R_0603_1608Metric
SW1: PowerOn; SW_Angled_with_GND
SW2: EVQWKL001; Encoder_EVQWK4
U1: ISL9204; DFN-8-1EP_3x2mm_P0.5mm_EP1.75x1.65mm
U2: TPS60241DGKR; TSSOP-8_3x3mm_P0.65mm
U3, U5: HT7333; SOT-89-3
U4: STM32H750VITx; LQFP-100_14x14mm_P0.5mm
Y1: 8 MHz; Crystal_SMD_5032-2Pin_5.0x3.2mm

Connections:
8Mhz: U4.67 (PA8); also elsewhere on the board
+3.3VA: C20.1, C21.1, L2.2, U4.21 (VDDA)
+3V3: C1.1, C2.1, C3.1, C4.1, C5.1, C23.1, J1.4, J3.1, J4.2, J4.9, R13.2, R14.1, R15.2, U4.6 (VBAT), U4.11 (VDD), U4.27 (VDD), U4.50 (VDD), U4.75 (VDD), U4.100 (VDD), U5.3 (OUT)
+5V: C15.1, L1.2; also elsewhere on the board
+5VP: D1.2 (A), J2.1 (VBUS), U1.1 (Vin)
+BATT: C12.1, R4.2, SW1.3 (C), U2.2 (EN), U2.6 (Vin), U3.2 (IN), U5.2 (IN); also elsewhere on the board
/ADC12_INP4: U4.32 (PC4)
/ENC_A: C24.1, R13.1, SW2.A, U4.93 (PB7)
/ENC_B: C26.2, R15.1, SW2.B, U4.92 (PB6)
/ENC_S: C25.2, R14.2, SW2.S2, U4.85 (PD4)
/NRST: C7.1, J1.3, U4.14 (NRST)
/SWD_IO: J1.1, U4.72 (PA13)
/SWD_SCK: J1.2, U4.76 (PA14)
/TFT_CS: J4.7, R12.2
/TFT_D_C: J4.5, R7.1
/TFT_MISO: J4.1, R9.1
/TFT_MOSI: J4.4, R10.1
/TFT_RESET: J4.6, R11.2
/TFT_SCK: J4.3, R8.1
/UART1_RX: U4.69 (PA10)
/UART1_TX: U4.68 (PA9)
/UART2_RX: J3.3, U4.87 (PD6)
/UART2_TX: J3.2, U4.86 (PD5)
/USB_DM: J2.2 (D-), U4.70 (PA11)
/USB_DP: J2.3 (D+), U4.71 (PA12)
ADC12_INP3: U4.30 (PA6); also elsewhere on the board
ADC12_INP5: C11.1, R4.1, R5.2, U4.35 (PB1)
ADC_DATA: U4.44 (PE14); also elsewhere on the board
ADC_SCK: U4.42 (PE12); also elsewhere on the board
EN_V: U4.97 (PE0); also elsewhere on the board
GND: BT1.2 (-), C1.2, C2.2, C3.2, C4.2, C5.2, C6.2, C7.2, C8.2, C9.2, C10.2, C11.2, C12.2, C13.2, C15.2, C18.2, C19.2, C20.2, C21.2, C22.2, C23.2, C24.2, C25.1, C26.1, J1.5, J2.5 (GND), J2.6 (Shield), J3.4, J4.8, R1.1, R3.1, R5.1, R6.1, SW2.C, SW2.GND, SW2.PAD, SW2.S1, U1.4 (~EN), U1.5 (GND), U1.9 (EPAD), U2.4 (GND), U3.1 (GND), U4.10 (VSS), U4.19 (VSSA), U4.26 (VSS), U4.49 (VSS), U4.74 (VSS), U4.94 (BOOT0), U4.99 (VSS), U5.1 (GND); also elsewhere on the board
unnamed: BT1.1 (+), C6.1, SW1.2 (B), U1.8 (BAT)
unnamed: C8.1, U4.48 (VCAP1)
unnamed: C9.1, U4.73 (VCAP2)
unnamed: C10.1, U4.20 (VREF+)
unnamed: C13.1, L1.1, U2.1 (Vout)
unnamed: C16.1, U2.5 (C1-)
unnamed: C16.2, U2.7 (C1+)
unnamed: C17.1, U2.3 (C2-)
unnamed: C17.2, U2.8 (C2+)
unnamed: C18.1, U4.12 (PH0), Y1.1
unnamed: C19.1, U4.13 (PH1), Y1.2
unnamed: C22.1, L2.1, R6.2, U3.3 (OUT)
unnamed: D1.1 (K), R2.2
unnamed: R1.2, U1.7 (IREF)
unnamed: R2.1, U1.3 (~CHG)
unnamed: R3.2, U1.6 (IMIN)
unnamed: R7.2, U4.51 (PB12)
unnamed: R8.2, U4.52 (PB13)
unnamed: R9.2, U4.53 (PB14)
unnamed: R10.2, U4.54 (PB15)
unnamed: R11.1, U4.55 (PD8)
unnamed: R12.1, U4.56 (PD9)
ON_1: U4.39 (PE9); also elsewhere on the board
ON_10: U4.38 (PE8); also elsewhere on the board
ON_100: U4.37 (PE7); also elsewhere on the board

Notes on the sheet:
200mA charge current
TFT_LED
StepUp +5V Max 25 mA
PB3 - SPI1_SCK PB4 - SPI1_MISO PB5 - SPI1_MOSI
PC10 - SPI3_SCK PC11 - SPI3_MISO PC12 - SPI3_MOSI
PB6 - TIM4_CH1 PB7 - TIM4_CH2
PA5 - SPI1_SCK
PA7 - SPI1_MOSI
PE12 - SPI4_SCK PE13 - SPI4_MISO PE14 - SPI4_MOSI
R7-R12 попробуем 300 Ом


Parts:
C14, C31, C32, C42, C43: 22n; C_0603_1608Metric
C27: 22; C_0603_1608Metric
C28: 10u; C_1206_3216Metric
C29, C30, C36, C37, C38: 100n; C_0603_1608Metric
C33: 10n; C_0603_1608Metric
C34: 25u; C_1206_3216Metric
C35, C40: 2.2u; C_0805_2012Metric
C39: 1.5n; C_1206_3216Metric
C41: 100u; C_1206_3216Metric
J5: Vout; Pin_D1.0mm_L10.0mm_LooseFit
J6: Isense; Pin_D1.0mm_L10.0mm_LooseFit
J7: GND; Pin_D1.0mm_L10.0mm_LooseFit
Q1, Q2: SI2302; SOT-23
Q3: IRLML2502; SOT-23
R16, R20: 2k; R_0603_1608Metric
R17, R18, R21, R23, R24, R25: 10k; R_0603_1608Metric
R19: 1; R_0603_1608Metric
R22: 4.7; R_0603_1608Metric
R26, R27, R28, R36: 5.1k; R_0603_1608Metric
R29: 1k; R_0603_1608Metric
R30: 100; R_0603_1608Metric
R31: 10; R_0603_1608Metric
R32: 1; R_0805_2012Metric
R33, R34, R35: 4.7k; R_0603_1608Metric
R37, R38, R39: 68k; R_0603_1608Metric
R40: 220; R_0603_1608Metric
R41: 30; R_0603_1608Metric
RV1: 20k; Potentiometer_10mm
U6: LM4140; SO-8_3.9x4.9mm_P1.27mm
U7: TPS79301-EP; SOT-23-6
U8: AD8031; SOT-23-5
U9: INA240A1PW; TSSOP-8_4.4x3mm_P0.65mm
U10: ADS1251; SOIC-8_3.9x4.9mm_P1.27mm

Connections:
8Mhz: R41.2; also elsewhere on the board
+5V: C29.1, C30.1, C36.1, C37.1, U6.2 (Vin), U6.3 (Enable), U8.5 (V+), U9.5 (V+), U10.3 (VCC); also elsewhere on the board
+BATT: U7.1 (IN); also elsewhere on the board
/analog/2.0V: C40.1, C41.1, R22.2, R36.1, U9.6 (REF2), U9.7 (REF1)
/analog/4.096V: C28.1, C38.1, R17.1, U6.6 (Vref), U10.8 (VREF)
/analog/Vout: C27.1, C34.1, J5.1, R16.1, RV1.1, RV1.2, U7.6 (OUT)
ADC12_INP3: C32.1, R16.2, R20.1; also elsewhere on the board
ADC_DATA: R25.2, R28.2; also elsewhere on the board
ADC_SCK: R24.2, R26.2; also elsewhere on the board
EN_V: R18.1; also elsewhere on the board
GND: C14.2, C29.2, C30.2, C31.2, C32.2, C33.2, C34.2, C35.2, C36.2, C37.2, C38.2, C41.2, C42.2, C43.2, J7.1, Q1.2 (S), Q2.2 (S), Q3.2 (S), R19.2, R20.2, R21.2, R23.2, R24.1, R25.1, R29.2, R37.2, R38.2, R39.2, R40.2, U6.1 (GND), U6.4 (GND), U6.7 (GND), U6.8 (GND), U7.2 (GND), U8.2 (V-), U9.1 (GND), U9.3 (-), U9.4 (GND), U10.7 (GND); also elsewhere on the board
unnamed: C14.1, Q1.1 (G), R33.2, R37.1
unnamed: C27.2, R21.1, RV1.3, U7.5 (FB)
unnamed: C28.2, R19.1
unnamed: C31.1, R18.2, U7.3 (EN)
unnamed: C33.1, U7.4 (BP)
unnamed: C35.1, R17.2, R23.1, U8.3 (+)
unnamed: C39.1, R27.2, U10.1 (IN+)
unnamed: C39.2, R36.2, U10.2 (IN-)
unnamed: C40.2, R40.1
unnamed: C42.1, Q2.1 (G), R34.2, R38.1
unnamed: C43.1, Q3.1 (G), R35.2, R39.1
unnamed: J6.1, R29.1, R30.1, R31.1, R32.1, U9.2 (+)
unnamed: Q1.3 (D), R30.2
unnamed: Q2.3 (D), R31.2
unnamed: Q3.3 (D), R32.2
unnamed: R22.1, U8.1, U8.4 (-)
unnamed: R26.1, U10.6 (SCLK)
unnamed: R27.1, U9.8
unnamed: R28.1, U10.5 (DOUT/nDRDY)
unnamed: R41.1, U10.4 (CLK)
ON_1: R35.1; also elsewhere on the board
ON_10: R34.1; also elsewhere on the board
ON_100: R33.1; also elsewhere on the board

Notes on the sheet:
Выход напряжения с прибора.


Board: 2 copper layers, 80.0 x 65.0 mm, 112 parts (0 on the bottom side), 76 nets.

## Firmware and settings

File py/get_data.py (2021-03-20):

#!/usr/bin/env python3

import time
import serial
import sys
import struct
import xml.etree.ElementTree as ET

USB_COMMAND_ADC_BUFFER_START = 0x6BDE0001
USB_COMMAND_ADC_BUFFER_GET = 0x6BDE0002
USB_COMMAND_ADC_BUFFER_STATUS = 0x6BDE0003
USB_COMMAND_NANOAMPERS = 0x6BDE0004
USB_COMMAND_ST_INFO = 0x6BDE0005
USB_COMMAND_ST_DATA = 0x6BDE0006


ser = None

def connect():
	global ser
	ser = serial.Serial(
		port='/dev/ttyACM0',
		baudrate=500000,
		parity=serial.PARITY_NONE,
		stopbits=serial.STOPBITS_ONE,
		bytesize=serial.EIGHTBITS,
		timeout = 0.2
	)

	return ser.isOpen()

def close():
	ser.close()

def StartSampling():
	ser.write(struct.pack("I",USB_COMMAND_ADC_BUFFER_START))
	time.sleep(0.1)
	data = ser.read_all()
	if len(data)!=4:
		print("StartSampling timeout")
		return False
	result = struct.unpack("I", data)[0]
	print("res=", result)
	if result==0x12345:
		print("Started succefully")
	else:
		print("StartSampling unexpected error")
		return False


	while True:
		ser.write(struct.pack("I",USB_COMMAND_ADC_BUFFER_STATUS))
		time.sleep(0.1)
		data = ser.read_all()
		if len(data)!=4:
			print("StartSampling status timeout")
			return False

		if(len(data)==4):
			value = struct.unpack("I", data)[0]
			print("status=", hex(value))
			if value:
				return True

		elif(len(data)>256):
			print("len(data)=", len(data))
		else:
			print("value=", data)
		time.sleep(0.1)
	return False


def ReceiveData(filename, command, all_size = 0x8000*4):
	ser.write(struct.pack("I", command))
	print("Data query.")
	f = open(filename, "wb")
	sum_size = 0
	is_empty = False
	while True:
		data = ser.read_all()
		if len(data)==0:
			print(".", end='')
			sys.stdout.flush()
			time.sleep(1)
			continue

		if is_empty:
			print("")
		is_empty = False
		print("len(data)=", len(data))
		f.write(data)
		sum_size += len(data)
		if sum_size>=all_size:
			break
		time.sleep(0.01)
	f.close()
	print("Data received complete. size=", sum_size)
	return


class STInfo:
	def __init__(self, status, tilter_sps, trigger_offset, samples):
		self.status = status
		self.tilter_sps = tilter_sps
		self.trigger_offset = trigger_offset
		self.samples = samples

def ReceiveSTInfo():
	ser.write(struct.pack("I", USB_COMMAND_ST_INFO))
	time.sleep(0.1)
	data = ser.read_all()
	if len(data)!=16:
		print("ReceiveSTInfo bad data size=", len(data))
		return False
	(status, tilter_sps, trigger_offset, samples) = struct.unpack("IfII", data)
	return STInfo(status, tilter_sps, trigger_offset, samples)


def main():
	if not connect():
		print("Cannot connect to serial port")
		exit(1)

	if False:
		filename = "data.bin"
		if len(sys.argv)>2:
			filename = sys.argv[2]
		print("filename=",filename)
		StartSampling()
		ReceiveData(filename=filename, command=USB_COMMAND_ADC_BUFFER_GET)
		return

	if False:	
		filename = "data.na"
		if len(sys.argv)>2:
			filename = sys.argv[2]
		print("filename=",filename)
		ReceiveData(filename=filename, command=USB_COMMAND_NANOAMPERS)
		return
	
	if True:
		info = ReceiveSTInfo()
		print("status =", info.status)
		print("tilter_sps =", info.tilter_sps)
		print("trigger_offset =", info.trigger_offset)
		print("samples =", info.samples)

		if info.status==6 and info.samples>100:
			ReceiveData("out.a", command=USB_COMMAND_ST_DATA, all_size=info.samples*4)
		return

	pass

def help():
	print("Receive data from Microampermeter")

if __name__ == "__main__":
	if len(sys.argv)==1:
		help()
	#print(sys.argv)
	#print(g_standart_freq)
	#print(FreqListX(4))
	main()

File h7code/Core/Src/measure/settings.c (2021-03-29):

#include "main.h"

#include "settings.h"
#include "hardware/store_to_spi_flash.h"
#include "my_filter.h"
#include "gui/scene_single.h"
#include "gui/menu_trigger_level.h"

enum
{
    SETTINGS_SECTOR = 0,
    SETTINGS_PERMANENT_SECTOR = 1,
};

Settings g_settings;
SettingsPermanent g_settings_permanent;
bool g_settings_is_changed = false;
uint32_t g_settings_last_change_or_save_time = 0;
int debug_save_settings_count = 0;

float mul_V_original;
float mul_I_original;
static float resistor_value_inv[RESISTOR_1_Om+1];

static void UpdateRinv();
static float GetResistorValueOriginal(RESISTOR r);

void InitSettings()
{
    g_settings.offset_adc_I = 0;
    g_settings.offset_adc_V = 0;

    g_settings.line2_type = line2_type;
    g_settings.filterX = g_filterX;
    g_settings.scene_id = 0;
    g_settings.sum_histogramm_time = 0;
    g_settings.seconds_per_line_idx = 0;
    g_settings.ampers_per_line_idx = 0;
    g_settings.oscilloscope_encoder = 0;
    g_settings.trigger_level = TRIGGER_LEVEL_10uA;
    g_settings.trigger_rising = 1;
    g_settings.dummy0 = 0;
    g_settings.dummy1 = 0;
    g_settings.dummy2 = 0;
}

void InitSettingsPermanent()
{
    float ku = 10;
    float Vref = 2.0;
    //float korr = 1/0.9625f; //Коррекция тока
    mul_I_original = Vref/(1<<23)/ku;//*korr;

    mul_V_original = 1/ku*//ОУ
        1/0.027f*//Резистивный делитель
        Vref*//Напряжение Vref
        1.f/(1<<23);

    g_settings_permanent.mul_I = mul_I_original;
    g_settings_permanent.mul_V = mul_V_original;

    g_settings_permanent.R_100_Om = GetResistorValueOriginal(RESISTOR_100_Om);
    g_settings_permanent.R_10_Om = GetResistorValueOriginal(RESISTOR_10_Om);
    g_settings_permanent.R_1_Om = GetResistorValueOriginal(RESISTOR_1_Om);
    UpdateRinv();
}

bool LoadSettings()
{
    bool ok = SpiFlashReadFromFlash(SETTINGS_SECTOR, sizeof(g_settings), &g_settings);
    if(ok)
    {
        if(g_settings.filterX > FilterX_1024)
            g_settings.filterX = FilterX_1;

        if(g_settings.trigger_level >= TRIGGER_LEVEL_COUNT)
            g_settings.trigger_level = TRIGGER_LEVEL_10uA;

        line2_type = g_settings.line2_type;
        g_filterX = g_settings.filterX;
    }
    return ok;
}

bool SaveSettings()
{
    g_settings_is_changed = false;
    g_settings_last_change_or_save_time = TimeMs();
    debug_save_settings_count++;

    g_settings.line2_type = line2_type;
    g_settings.filterX = g_filterX;
    return SpiFlashWriteToFlash(SETTINGS_SECTOR, sizeof(g_settings), &g_settings);
}

bool LoadSettingsPermanent()
{
    bool ok = SpiFlashReadFromFlash(SETTINGS_PERMANENT_SECTOR, sizeof(g_settings_permanent), &g_settings_permanent);
    UpdateRinv();
    return ok;
}

bool SaveSettingsPermanent()
{
    return SpiFlashWriteToFlash(SETTINGS_PERMANENT_SECTOR, sizeof(g_settings_permanent), &g_settings_permanent);
}

static float PAR(float R1, float R2)
{
    return R1*R2/(R1+R2);
}

float GetResistorValueOriginal(RESISTOR r)
{
    float R1K = 1000;
    float R100 = 100;
    float R10 = 10;
    float R1 = 1.2f;

    switch(r)
    {
    default:
    case RESISTOR_1_Kom: return R1K;
    case RESISTOR_100_Om: return PAR(R1K, R100);
    case RESISTOR_10_Om: return PAR(R1K, R10);
    case RESISTOR_1_Om: return PAR(R1K, R1);
    }
}

float GetResistorValue(RESISTOR r)
{
    float R1K = 1000;

    switch(r)
    {
    default:
    case RESISTOR_1_Kom: return R1K;
    case RESISTOR_100_Om: return g_settings_permanent.R_100_Om;
    case RESISTOR_10_Om: return g_settings_permanent.R_10_Om;
    case RESISTOR_1_Om: return g_settings_permanent.R_1_Om;
    }
}

float GetResistorValueInv(RESISTOR r)
{
    return resistor_value_inv[r];
}

void UpdateRinv()
{
    resistor_value_inv[RESISTOR_1_Kom] = 1.f/GetResistorValue(RESISTOR_1_Kom);
    resistor_value_inv[RESISTOR_100_Om] = 1.f/g_settings_permanent.R_100_Om;
    resistor_value_inv[RESISTOR_10_Om] = 1.f/g_settings_permanent.R_10_Om;
    resistor_value_inv[RESISTOR_1_Om] = 1.f/g_settings_permanent.R_1_Om;
}

float TriggerLevelAmpers()
{
    switch(g_settings.trigger_level)
    {
    case TRIGGER_LEVEL_1uA: return 1e-6f;
    case TRIGGER_LEVEL_2uA: return 2e-6f;
    case TRIGGER_LEVEL_5uA: return 5e-6f;
    case TRIGGER_LEVEL_10uA: return 10e-6f;
    case TRIGGER_LEVEL_20uA: return 20e-6f;
    case TRIGGER_LEVEL_50uA: return 50e-6f;
    case TRIGGER_LEVEL_100uA: return 100e-6f;
    case TRIGGER_LEVEL_200uA: return 200e-6f;
    case TRIGGER_LEVEL_500uA: return 500e-6f;
    case TRIGGER_LEVEL_1mA: return 1e-3f;
    case TRIGGER_LEVEL_2mA: return 2e-3f;
    case TRIGGER_LEVEL_5mA: return 5e-3f;
    case TRIGGER_LEVEL_10mA: return 10e-3f;
    }

    return 10e-6f;
}

void SaveSettingsLazy()
{
    g_settings_is_changed = true;
    g_settings_last_change_or_save_time = TimeMs();
}

void SettingsLazyQuant()
{
    if(!g_settings_is_changed)
        return;

    uint32_t dt = TimeMs()-g_settings_last_change_or_save_time;
    if(dt < 3000)
        return;

    SaveSettings();
}

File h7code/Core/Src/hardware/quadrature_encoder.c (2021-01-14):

#include "stm32h7xx_hal.h"
#include "quadrature_encoder.h"

void Error_Handler(void);

//-------------------------------------------#DEFINE------------------------------------------
//Encoder PB6, PB7 TIM4
#define Codeur1_A           GPIO_PIN_6
#define Codeur1_B           GPIO_PIN_7
#define Codeur1_GPIO        GPIOB
#define Codeur1_AF          GPIO_AF2_TIM4
#define Codeur1_TIMER       TIM4

#ifdef DISPLAY_ILI9341
#define BUTTON_PIN1         GPIO_PIN_4
#define BUTTON_GPIO			GPIOD
#else
#define BUTTON_PIN1         GPIO_PIN_8
#define BUTTON_GPIO			GPIOB
#endif

static TIM_HandleTypeDef    tim_init;
static TIM_Encoder_InitTypeDef encoder;

void QuadEncInit()
{
    __HAL_RCC_GPIOB_CLK_ENABLE();
    __HAL_RCC_GPIOD_CLK_ENABLE();
    __HAL_RCC_TIM4_CLK_ENABLE();


    tim_init.Instance = Codeur1_TIMER;
    tim_init.Init.Period = 0xffff;
    tim_init.Init.Prescaler = 0;
    tim_init.Init.CounterMode = TIM_COUNTERMODE_UP;
    tim_init.Init.ClockDivision = TIM_CLOCKDIVISION_DIV1;
    tim_init.Init.RepetitionCounter = 0;

    GPIO_InitTypeDef gpio = {};

    {//Codeur1
        // 2 Inputs for A and B Encoder Channels
        gpio.Pin = Codeur1_A|Codeur1_B;
        gpio.Mode = GPIO_MODE_AF_PP;
        gpio.Speed = GPIO_SPEED_HIGH;
        gpio.Pull = GPIO_NOPULL;
        gpio.Alternate = Codeur1_AF;
        HAL_GPIO_Init(Codeur1_GPIO, &gpio);
     
        encoder.EncoderMode = TIM_ENCODERMODE_TI12;

        encoder.IC1Filter = 0x0F;
        encoder.IC1Polarity = TIM_INPUTCHANNELPOLARITY_RISING;
        encoder.IC1Prescaler = TIM_ICPSC_DIV4;
        encoder.IC1Selection = TIM_ICSELECTION_DIRECTTI;

        encoder.IC2Filter = 0x0F;
        encoder.IC2Polarity = TIM_INPUTCHANNELPOLARITY_FALLING;
        encoder.IC2Prescaler = TIM_ICPSC_DIV4;
        encoder.IC2Selection = TIM_ICSELECTION_DIRECTTI;

        if (HAL_TIM_Encoder_Init(&tim_init, &encoder) != HAL_OK) {
            Error_Handler();
        }

        if(HAL_TIM_Encoder_Start(&tim_init, TIM_CHANNEL_ALL)!=HAL_OK){
            Error_Handler();
        }

    }

    //button
    gpio.Mode = GPIO_MODE_INPUT;
    gpio.Speed = GPIO_SPEED_LOW;
    gpio.Pull = GPIO_NOPULL;
    gpio.Pin = BUTTON_PIN1;
    HAL_GPIO_Init(BUTTON_GPIO, &gpio);
}

int16_t QuadEncValue()
{
    return (int16_t)Codeur1_TIMER->CNT;
}

bool QuadEncButton()
{
    return HAL_GPIO_ReadPin(BUTTON_GPIO, BUTTON_PIN1)==0;
}

/*
    срабатывание кнопки
    подавляем программный дребезг
    если кнопка нажата, то второй раз не отсылаем, что нажата
*/
typedef struct EncButtonData
{
    //Время предыдущего нажатия кнопки.
    uint16_t last_pressed_ms;
    uint16_t last_unpressed_ms;
    bool is_logical_pessed;
    bool is_hardware_pessed;
} EncButtonData;

static EncButtonData button = {};

static bool EncButtonPressedInternal(EncButtonData* data, bool hardware_pressed)
{
    uint16_t cur_time = HAL_GetTick();
    uint16_t dt_pressed = cur_time-data->last_pressed_ms;
    uint16_t dt_unpressed = cur_time-data->last_unpressed_ms;

    if(hardware_pressed)
    {
        if(!data->is_hardware_pessed)
        {
            data->is_hardware_pessed = true;
            data->last_pressed_ms = cur_time;
        }

        if(!data->is_logical_pessed)
        {
            data->is_logical_pessed = true;
            return true;
        }
    } else
    {
        if(data->is_hardware_pessed)
        {
            data->is_hardware_pessed = false;
            data->last_unpressed_ms = cur_time;
        }

        if(dt_pressed>200 && dt_unpressed>100)
        {
            data->is_logical_pessed = false;
        }
    }

    return false;
}

bool EncButtonPressed()
{
    return EncButtonPressedInternal(&button, QuadEncButton());
}

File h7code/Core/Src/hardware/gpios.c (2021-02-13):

#include "stm32h7xx_hal.h"
#include "gpios.h"

#define RESISTOR_PORT GPIOA
#define RESISTOR_PIN_100_Om GPIO_PIN_3
#define RESISTOR_PIN_10_Om  GPIO_PIN_2
#define RESISTOR_PIN_1_Om   GPIO_PIN_1

#define EN_V_PORT GPIOA
#define EN_V_PIN  GPIO_PIN_0

static RESISTOR last_r;

void GpiosInit()
{
    GPIO_InitTypeDef  gpio = {};
    gpio.Pull      = GPIO_NOPULL;
    gpio.Speed     = GPIO_SPEED_FREQ_HIGH;

    gpio.Mode      = GPIO_MODE_OUTPUT_PP;
    gpio.Pin       = RESISTOR_PIN_100_Om|RESISTOR_PIN_10_Om|RESISTOR_PIN_1_Om;
    HAL_GPIO_Init(RESISTOR_PORT, &gpio);

    gpio.Pin       = EN_V_PIN;
    HAL_GPIO_Init(EN_V_PORT, &gpio);

    last_r = RESISTOR_1_Kom;
    SetEnableV(true);
}

void SetResistor(RESISTOR r)
{
    last_r = r;
    HAL_GPIO_WritePin(RESISTOR_PORT, RESISTOR_PIN_100_Om, r==RESISTOR_100_Om);
    HAL_GPIO_WritePin(RESISTOR_PORT, RESISTOR_PIN_10_Om, r==RESISTOR_10_Om);
    HAL_GPIO_WritePin(RESISTOR_PORT, RESISTOR_PIN_1_Om, r==RESISTOR_1_Om);
}

void SetEnableV(bool enable)
{
    HAL_GPIO_WritePin(EN_V_PORT, EN_V_PIN, enable);
}

RESISTOR GetResistor()
{
   return last_r;
}

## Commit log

2020-10-07 - kicad schematic
    [ampermeter.kicad_pcb, ampermeter.sch, analog.sch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]
2020-10-09 - изначальный коммит кода
    [ampermeter.sch, analog.sch, isolated_usb2uart.sch]
2020-10-09 - ADC заработало в простейшем режиме
2020-12-20 - изменения скопом, за огромный промежуток времени
    [ADS1271.kicad_pcb, ADS1271.sch, ad8606.kicad_pcb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]
2021-01-14 - новая графическая библиотека и более-менее работающий QSPI flash
2021-01-14 - работает, но со скоростью только 7 МБ/сек
2021-01-14 - QSPI MDMA 28 МБ/сек
2021-01-14 - проверили чтение запись всех 8 МБ памяти
2021-01-16 - мелкие изменения перед попыткой запустить SAI
2021-01-17 - работающий HAL_SAI_Receive_DMA причем похоже в правильных частотах
2021-01-17 - HAL_SAI_Receive_DMA не работает, HAL_SAI_Receive - выдаёт фигню
2021-01-17 - что-то выводит, но DMA не работает
2021-01-18 - получили какие-то разумные цифры с аналоговой части
    [ADS1271.sch, analog_frontend.kicad_pcb, analog_frontend.sch]
2021-01-18 - начинаем разносить код в разные файлы
2021-01-19 - слили данные на компьютер
2021-01-19 - program_release.bin был 650 МБ, добавили (NOLOAD) и стало 45 кб
    - корректно работает с отрицательными значениями ADC
2021-01-23 - попробовали компилировать clang
    - уточнили временно корректировку
2021-01-25 - передаются корректные данные на usb
    - множество мелких изменений
2021-01-27 - SendAdcCurrentNanoampers r shift & HAL_DMA_IRQHandlerSai
    HAL_DMA_IRQHandlerSai - укороченный вариант, чтобы побыстрее работало прерывание
    SendAdcCurrentNanoampers учитывает, что при переключении у нас есть большая задержка ADC (из-за фильтра встроенного в неё)
2021-01-27 - захардкодили DMA1_Stream0
2021-01-31 - небольшой рефактор, для того, чтобы было более удобно ввести задержку R
2021-01-31 - samples_r_buffer даёт требуемую задержку
2021-02-02 - считаем процент времени проведённый в прерывании
2021-02-02 - invalid samples в самом начале
2021-02-03 - вынес подсчет среднего в отдельный файл
2021-02-05 - вынесли начальный интерфейс в отдельный файл
2021-02-05 - более-менее пристойный вывод на экран
2021-02-06 - очень большой фонт, показываем % времени проведённого в прерывании
2021-02-06 - показываем минимальный/максимальный ток
2021-02-06 - фильтруем верхние частоты x16 для min/max
2021-02-07 - отделили подсчёт тока в отдельную функцию
2021-02-07 - фильтруем ток, а не adc_I
2021-02-07 - фильтруем с разной частотой, меню по этому поводу
2021-02-07 - переключение line2, исправили расчёт сопротивления
    [mid_big_interval.c]
2021-02-11 - попробовали писать во flash за пределы первой страницы (неудачно)
    - запаяли qspi flash и заставили её работать в spi режиме
    [stm32h7_digital.sch]
2021-02-11 - vbat напряжение на процессоре (но неточное)
2021-02-11 - battery full/empty
2021-02-11 - flash вроде работает корректно
2021-02-12 - calibration zero рабочий, calibration hard только начали
2021-02-13 - корректировка коэффициента усиления канала тока
2021-02-13 - настройки сопротивлений разных диапазонов
2021-02-13 - settings permanent запоминаются
    можно посмотреть на корректировочные коэффициенты
2021-02-14 - запоминаем настройки line2 и FilterX
2021-02-14 - начинаем делать гистограмму
2021-02-14 - начали заполнять цифрами вертикальную ось
2021-02-15 - шкала справа корректно обновляется
2021-02-16 - таки увидели реальную гистограмму
2021-02-18 - время суммирования гистограммы. Выбор microampermetr/histogramm
2021-03-03 - коробочка готовая (правда дырки сверлили под щупы)
2021-03-13 - отдельно калибруем offset voltage и offset current
    - кое-как завершил гистограммы
    [battery_holder.stl, microampermeter_bottom.stl, microampermeter_top.stl]
2021-03-14 - путь для тока и напряжения теперь более единообразен
2021-03-15 - проверенный циклический буфер
    - добавили пустую сцену для осциллоскопа
2021-03-20 - начали писать данные в огромный буффер
    - заодно исправили косяки при переключении диапазонов и отрицательном токе
    [get_data.py, main.c, mid_big_interval.c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]
2021-03-20 - окошко как в осциллографе прикрутили, 80 FPS отрисовывает
2021-03-21 - увидели первый график
2021-03-21 - scale current & time работают в меню
2021-03-21 - на заднем фоне рисуем min/max текущего значения
2021-03-23 - offset time работает в осциллографе
2021-03-26 - учитываем случай, когда линия одновременно выходит за границы сверху и снизу
2021-03-26 - нормальный график в случае, если данных меньше, чем пикселей
2021-03-28 - trigger started/completed теперь цветом отображается
    - first_sample_offset теперь не изменяется после того, как триггер сработал
    - progress bar теперь показывает сколько осталось до окончания сэмплирования, либо текущий offset на графике
2021-03-29 - теперь график единоразово обновляется в момент, когда сработал триггер и уже достаточно данных, чтобы на экране нарисовать
2021-03-29 - батарейку нарисовать в конце осциллографа
    - добавить Bandwidth в меню осциллографа
2021-03-29 - запись настроек отложенная
    - scene About
2021-03-30 - корректно определяем circle_buffer.first_sample_offset при срабатывании триггера
2021-04-15 - sch info text
    [analog_frontend.sch]
